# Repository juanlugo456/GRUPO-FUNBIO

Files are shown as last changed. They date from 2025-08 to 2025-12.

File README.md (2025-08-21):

# Grupo 1 FunBio
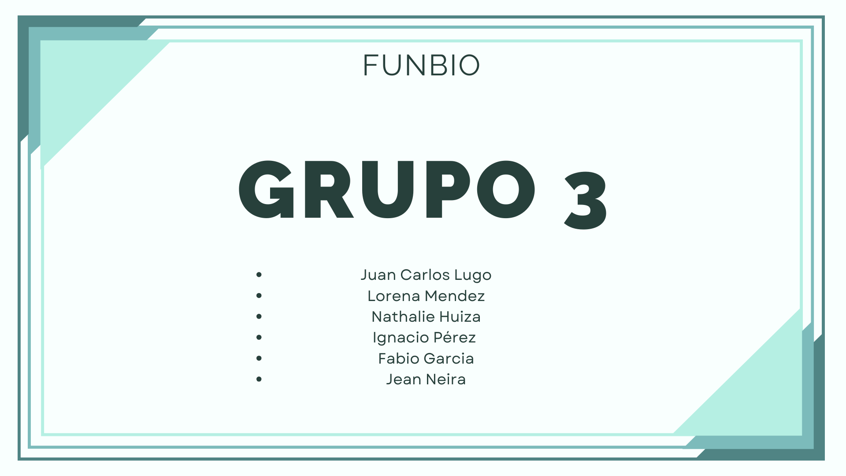
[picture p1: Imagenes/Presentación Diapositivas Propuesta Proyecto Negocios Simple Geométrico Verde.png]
Imagen_presentacion

## Equipo 3
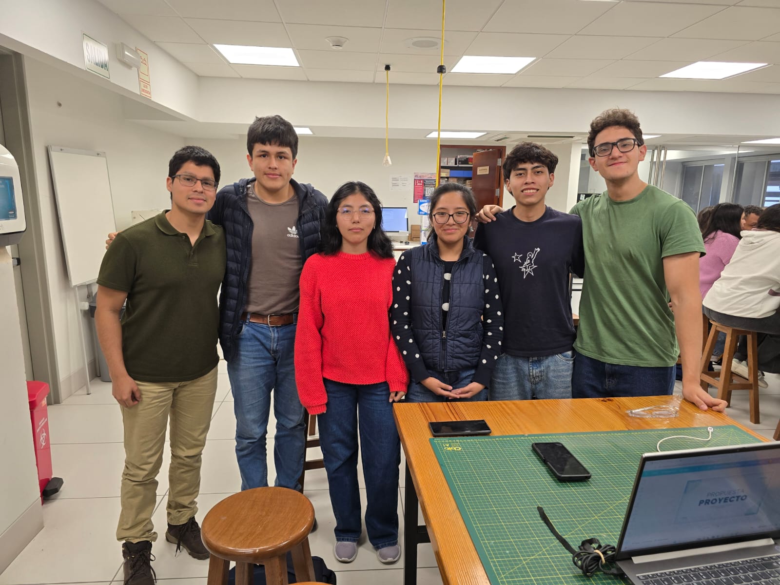
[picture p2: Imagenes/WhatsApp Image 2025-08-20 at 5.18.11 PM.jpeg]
Imagenfotogrupal

Somos alumnos de 4to ciclo de la carrera de Ingeniería Biomédica y estamos aquí para hacer el mundo un lugar mejor =).

## Miembros 
### Juan Carlos Lugo Rodriguez
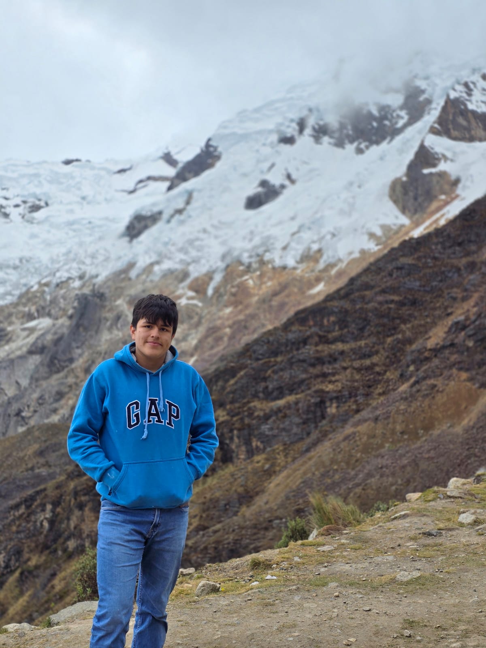
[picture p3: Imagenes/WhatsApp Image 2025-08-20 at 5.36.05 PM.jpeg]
Imagenfoto1
  
Edad:19 años    
Rol: Coordinador  
Responsabilidades:
- Estar pendientes de los avances del grupo
- Colaborar y ayudar en los avances
- Envio de los trabajos al Blackboard
### Ignacio Pérez Vargas
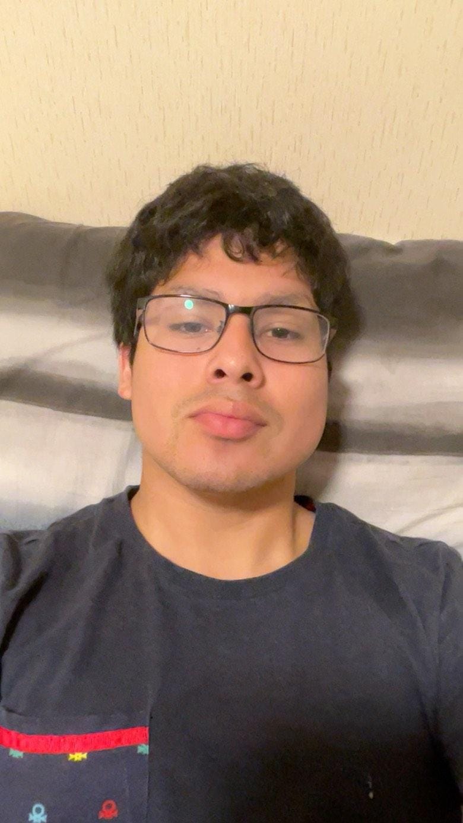
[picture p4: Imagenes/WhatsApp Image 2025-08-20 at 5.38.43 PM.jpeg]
Imagenfoto2
  
Edad: 18 años  
Rol: Programador y Prototipado  
Responsabilidades:
- Diseño 3D
- Elaboración de presentaciones e informes
- Prueba y ajuste.
### Lorena Mendez Saavedra  
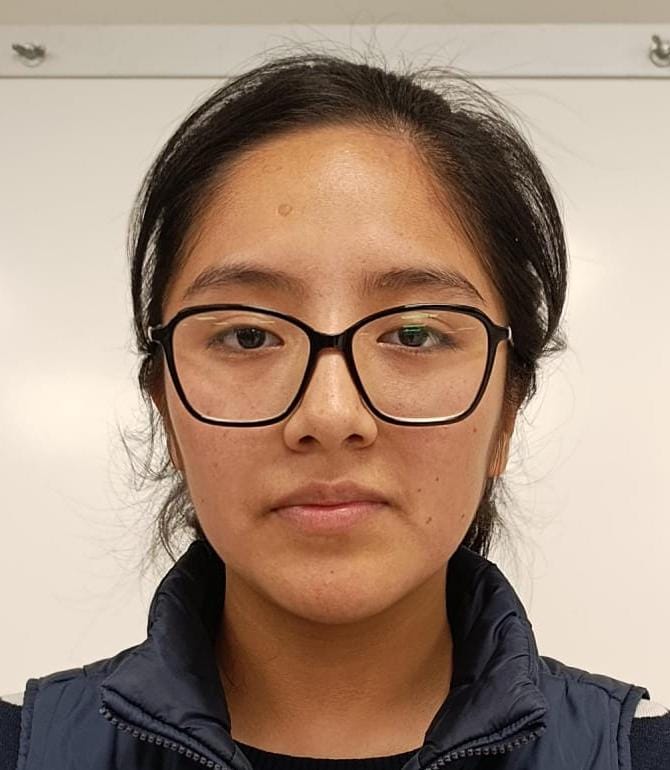
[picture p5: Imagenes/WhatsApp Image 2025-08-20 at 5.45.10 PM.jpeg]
Imagenfoto4
  
Edad: 18 años  
Rol: Gestor de repositorio  
Responsabilidades: 
- Actualizar información del trabajo
- Descargar y subir archivos(Repositorio)
### Nathalie Huiza  
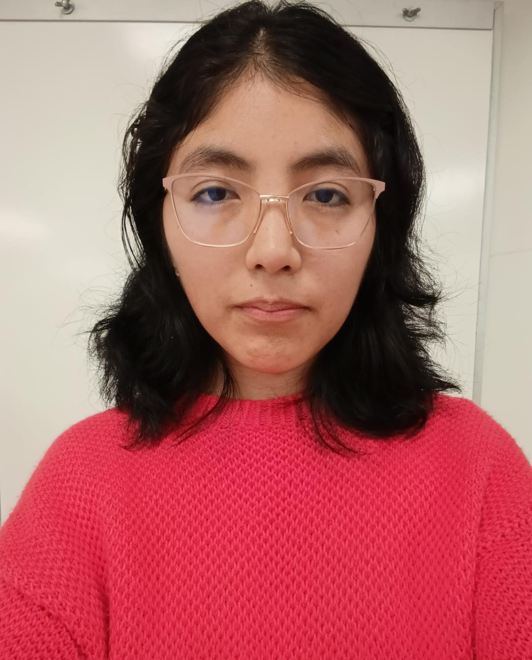
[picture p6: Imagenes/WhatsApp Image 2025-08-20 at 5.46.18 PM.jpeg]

Edad: 18  
Rol: Prototipado y armado  
Responsabilidad: 
- Diseño y prototipado
- Actualizar  información
- Pruebas finales
### Jean Neira
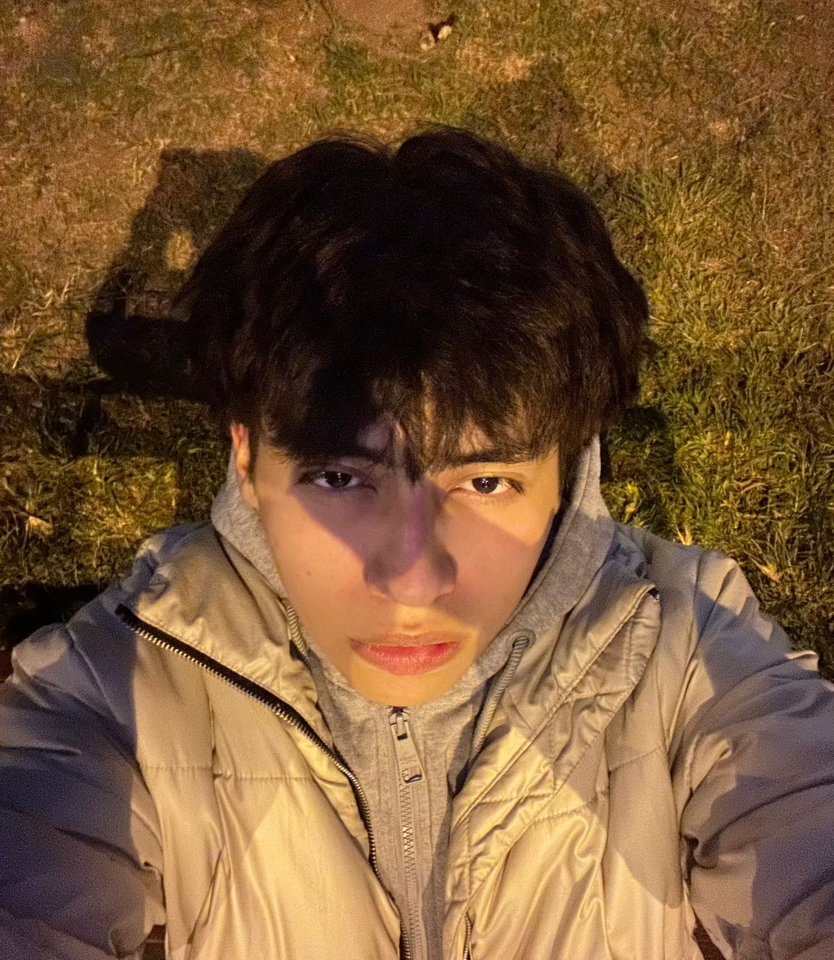
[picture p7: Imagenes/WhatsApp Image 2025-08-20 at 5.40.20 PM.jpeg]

Edad: 18  
Rol: Diseño y prototipado  
Responsabilidad: 
- Pruebas finales
- Registro de los materiales
- Apoyo moral
### Fabio Iván García Soto
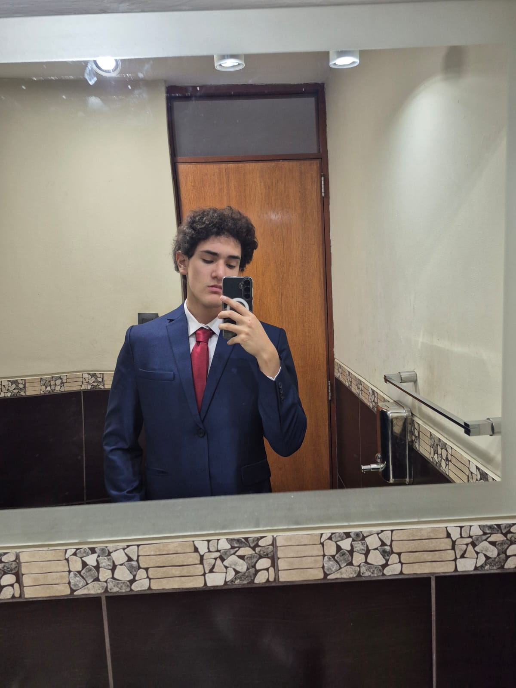
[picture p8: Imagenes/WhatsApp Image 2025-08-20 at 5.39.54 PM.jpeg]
Imagenfoto6

Edad: 19 años  
Rol: Diseño y programación  
Responsabilidades:
- Programación del prototipo
- Verificación del correcto funcionamiento del prototipo
- Prueba y ajuste.

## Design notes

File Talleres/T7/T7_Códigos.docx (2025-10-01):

Actividad 1_ Código

#include <Wire.h>

#include <LiquidCrystal_I2C.h>

#include <BluetoothSerial.h>

BluetoothSerial SerialBT;

LiquidCrystal_I2C lcd(0x27, 16, 2); // Dirección I2C del LCD (puede ser 0x3F en algunos módulos)

void setup() {

Serial.begin(115200);

SerialBT.begin("ESP32_LCD"); // Nombre Bluetooth

lcd.init();

lcd.backlight();

lcd.setCursor(0, 0);

lcd.print("Esperando BT...");

}

void loop() {

if (SerialBT.available()) {

String mensaje = SerialBT.readStringUntil('\n'); // Espera mensaje terminado en nueva línea

lcd.clear();

lcd.setCursor(0, 0);

// Si el mensaje es muy largo, dividir en dos líneas

if (mensaje.length() <= 16) {

lcd.print(mensaje);

} else {

lcd.print(mensaje.substring(0, 16));

lcd.setCursor(0, 1);

lcd.print(mensaje.substring(16, 32)); // 2da línea hasta 16 más

}

Serial.println("Mensaje recibido: " + mensaje);

}

}


Actividad 2_Código

#include <ESP32Servo.h>

#include "BluetoothSerial.h"

Servo servo;

BluetoothSerial BT;

const int SERVO_PIN = 2; // pin GPIO2 para el servo

String inbuf;

void setup() {

// Inicializa servo

ESP32PWM::allocateTimer(0);

ESP32PWM::allocateTimer(1);

ESP32PWM::allocateTimer(2);

ESP32PWM::allocateTimer(3);

servo.setPeriodHertz(50);

servo.attach(SERVO_PIN, 500, 2400);

servo.write(90); // posición inicial al centro

// Inicializa Bluetooth

BT.begin("ESP32_SERVO"); // Nombre para emparejar desde el celular

// BT.setPin("1234"); // Opcional: PIN de emparejamiento

}

void loop() {

while (BT.available()) {

char c = (char)BT.read();

if (c == '\r') continue; // Ignora retorno de carro

if (c == '\n') { // Fin de línea = comando completo

int angulo = inbuf.toInt(); // convierte a número

angulo = constrain(angulo, 0, 180); // limita entre 0 y 180

servo.write(angulo); // mueve el servo

BT.printf("Servo movido a %d grados\n", angulo);

inbuf = "";

} else {

inbuf += c;

if (inbuf.length() > 5) inbuf = ""; // seguridad

}

}

}

Codigo final de la 2da activdad

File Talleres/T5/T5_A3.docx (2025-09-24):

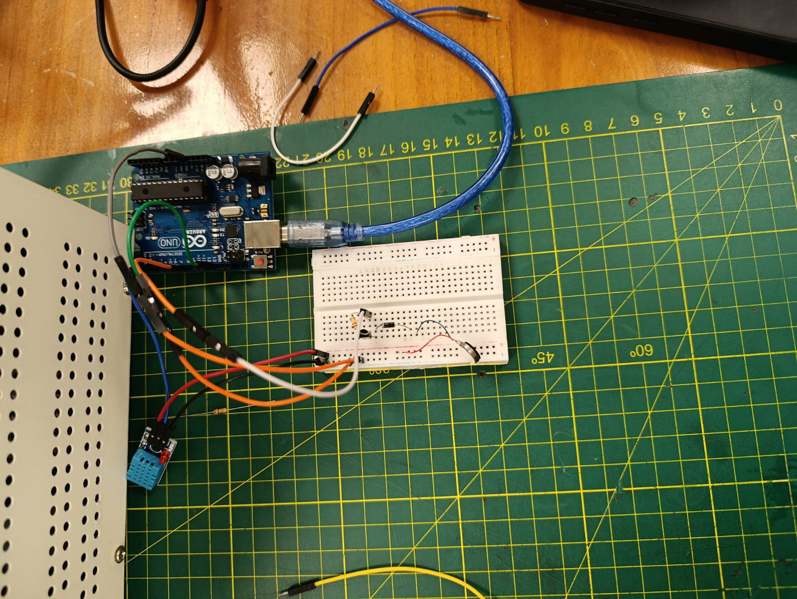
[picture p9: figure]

Código 3

#include <DHT.h>

#define DHTPIN 2 // Pin de datos del DHT11
#define DHTTYPE DHT11 // Tipo de sensor
#define MOTOR_PIN 9 // Pin PWM conectado a la base del 2N2222 (con resistencia)

DHT dht(DHTPIN, DHTTYPE);

void setup() {
Serial.begin(9600);
dht.begin();
pinMode(MOTOR_PIN, OUTPUT);
}

void loop() {
delay(2000); // DHT11 necesita tiempo entre lecturas

float temp = dht.readTemperature(); // Lee temperatura en °C

if (isnan(temp)) {
Serial.println("Error leyendo del DHT11!");
return;
}

Serial.print("Temperatura: ");
Serial.print(temp);
Serial.println(" *C");

int pwmValue = 0;

// Rango 1: 25–28 °C → Sin vibración
if (temp >= 25 && temp < 28) {
pwmValue = 0;
}
// Rango 2: 28–31 °C → Vibración media
else if (temp >= 28 && temp < 31) {
pwmValue = 128; // 50% duty cycle (0-255)
}
// Rango 3: 31–34 °C → Vibración alta
else if (temp >= 31 && temp <= 34) {
pwmValue = 220; // ~85% duty cycle
}
// Fuera de rango → motor apagado
else {
pwmValue = 0;
}

analogWrite(MOTOR_PIN, pwmValue);
}

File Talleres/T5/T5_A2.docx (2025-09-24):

“Código A2”
#include <Servo.h>

Servo servo;

int angulo;

int dato;

int pulso;

const int ledRojo = 8; // LED de alerta en pin 8

void setup() {

servo.attach(2); // Servo en pin 2

pinMode(ledRojo, OUTPUT);

Serial.begin(9600);

}

void loop() {

// Leer valor del flex sensor (0-1023)

dato = analogRead(A0);

// Mapear a ángulo de 0° a 270° (ajusta los valores mínimos y máximos de tu flex)

angulo = map(dato, 767, 964, 0, 270);

angulo = constrain(angulo, 0, 270); // Evitar valores fuera de rango

// Convertir ángulo a pulso (500–2400 µs)

pulso = map(angulo, 0, 270, 500, 2400);

// Enviar pulso al servo

servo.writeMicroseconds(pulso);

// Encender LED rojo si llega al máximo (270°)

if (angulo >= 270) {

digitalWrite(ledRojo, HIGH);

} else {

digitalWrite(ledRojo, LOW);

}

// Mostrar en Serial: ADC, pulso y ángulo

Serial.print("ADC: ");

Serial.print(dato);

Serial.print(" | Pulso (us): ");

Serial.print(pulso);

Serial.print(" | Angulo: ");

Serial.println(angulo);

delay(50);

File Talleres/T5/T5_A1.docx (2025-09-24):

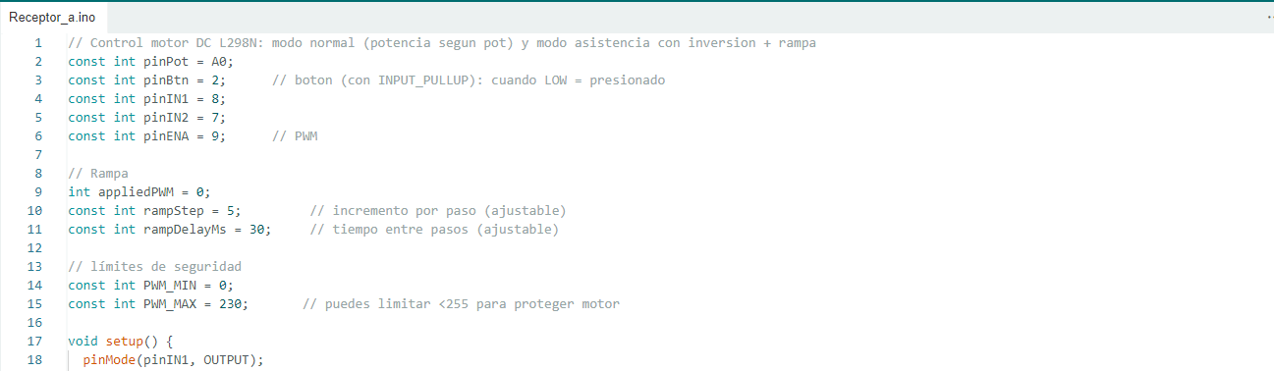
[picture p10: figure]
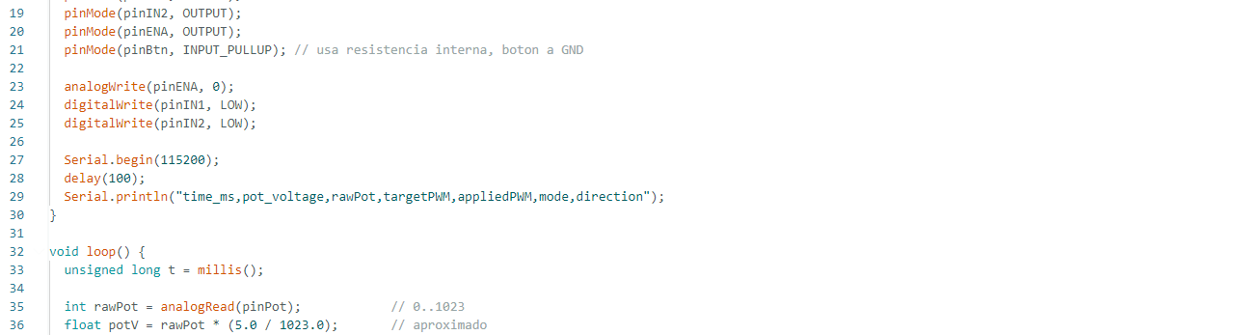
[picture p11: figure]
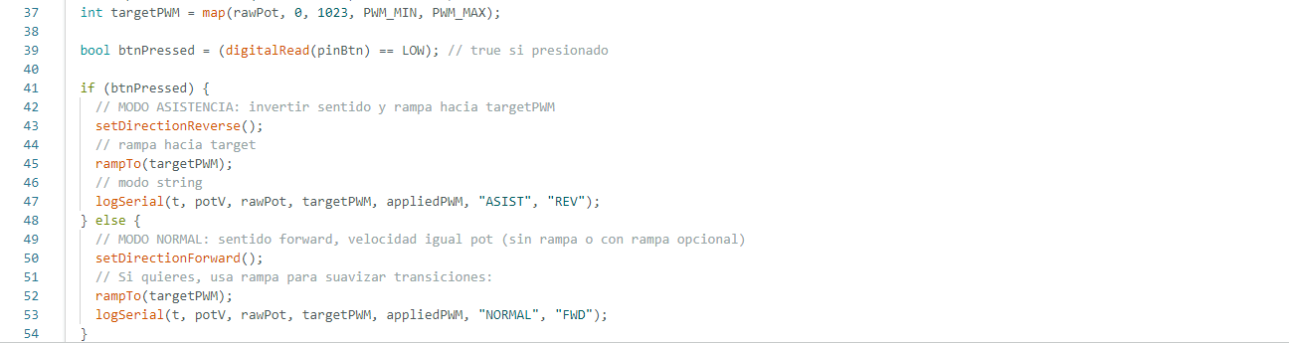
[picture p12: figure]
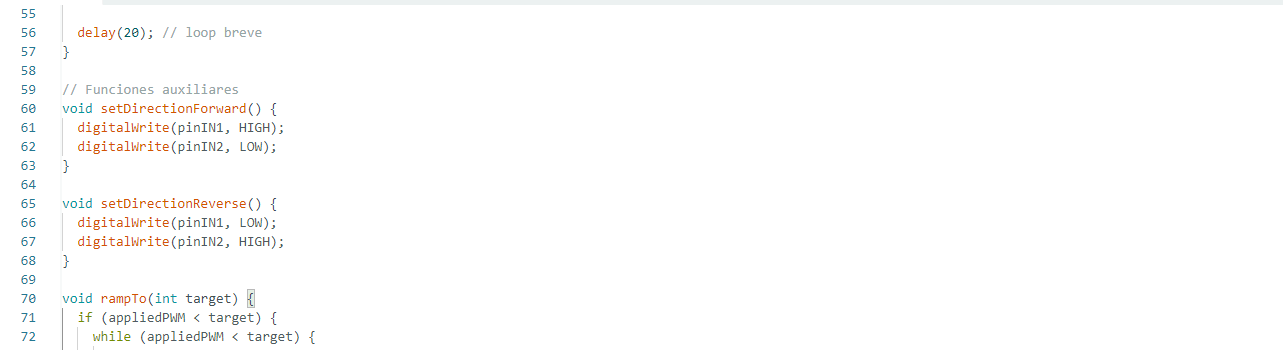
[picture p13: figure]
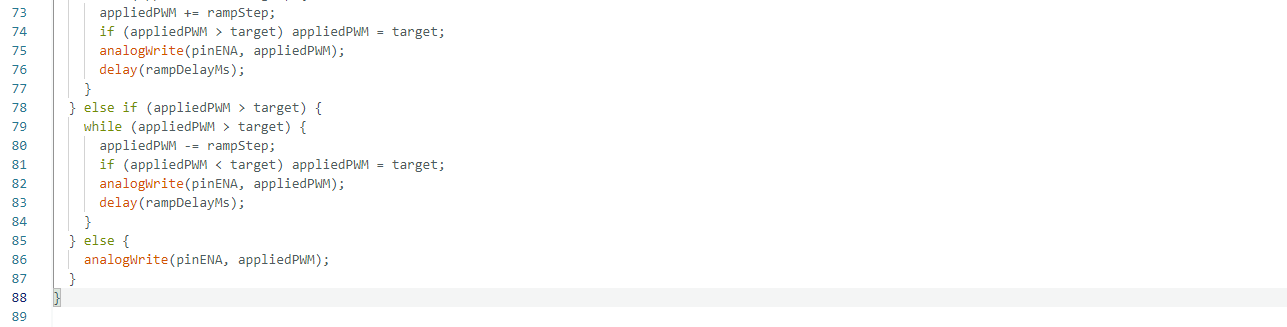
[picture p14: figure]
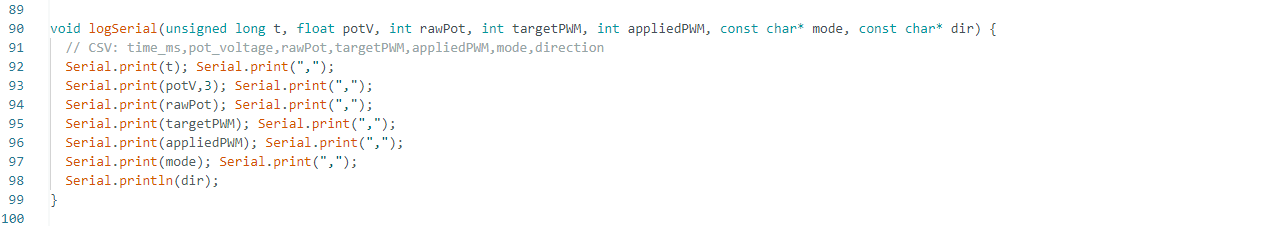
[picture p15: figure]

Còdigo

// Control motor DC L298N: modo normal (potencia segun pot) y modo asistencia con inversion + rampa

const int pinPot = A0;

const int pinBtn = 2; // boton (con INPUT_PULLUP): cuando LOW = presionado

const int pinIN1 = 8;

const int pinIN2 = 7;

const int pinENA = 9; // PWM

// Rampa

int appliedPWM = 0;

const int rampStep = 5; // incremento por paso (ajustable)

const int rampDelayMs = 30; // tiempo entre pasos (ajustable)

// límites de seguridad

const int PWM_MIN = 0;

const int PWM_MAX = 230; // puedes limitar <255 para proteger motor

void setup() {

pinMode(pinIN1, OUTPUT);

pinMode(pinIN2, OUTPUT);

pinMode(pinENA, OUTPUT);

pinMode(pinBtn, INPUT_PULLUP); // usa resistencia interna, boton a GND

analogWrite(pinENA, 0);

digitalWrite(pinIN1, LOW);

digitalWrite(pinIN2, LOW);

Serial.begin(115200);

delay(100);

Serial.println("time_ms,pot_voltage,rawPot,targetPWM,appliedPWM,mode,direction");

}

void loop() {

unsigned long t = millis();

int rawPot = analogRead(pinPot); // 0..1023

float potV = rawPot * (5.0 / 1023.0); // aproximado

int targetPWM = map(rawPot, 0, 1023, PWM_MIN, PWM_MAX);

bool btnPressed = (digitalRead(pinBtn) == LOW); // true si presionado

if (btnPressed) {

// MODO ASISTENCIA: invertir sentido y rampa hacia targetPWM

setDirectionReverse();

// rampa hacia target

rampTo(targetPWM);

// modo string

logSerial(t, potV, rawPot, targetPWM, appliedPWM, "ASIST", "REV");

} else {

// MODO NORMAL: sentido forward, velocidad igual pot (sin rampa o con rampa opcional)

setDirectionForward();

// Si quieres, usa rampa para suavizar transiciones:

rampTo(targetPWM);

logSerial(t, potV, rawPot, targetPWM, appliedPWM, "NORMAL", "FWD");

}

delay(20); // loop breve

}

// Funciones auxiliares

void setDirectionForward() {

digitalWrite(pinIN1, HIGH);

digitalWrite(pinIN2, LOW);

}

void setDirectionReverse() {

digitalWrite(pinIN1, LOW);

digitalWrite(pinIN2, HIGH);

}

void rampTo(int target) {

if (appliedPWM < target) {

while (appliedPWM < target) {

appliedPWM += rampStep;

if (appliedPWM > target) appliedPWM = target;

analogWrite(pinENA, appliedPWM);

delay(rampDelayMs);

}

} else if (appliedPWM > target) {

while (appliedPWM > target) {

appliedPWM -= rampStep;

if (appliedPWM < target) appliedPWM = target;

analogWrite(pinENA, appliedPWM);

delay(rampDelayMs);

}

} else {

analogWrite(pinENA, appliedPWM);

}

}

void logSerial(unsigned long t, float potV, int rawPot, int targetPWM, int appliedPWM, const char* mode, const char* dir) {

// CSV: time_ms,pot_voltage,rawPot,targetPWM,appliedPWM,mode,direction

Serial.print(t); Serial.print(",");

Serial.print(potV,3); Serial.print(",");

Serial.print(rawPot); Serial.print(",");

Serial.print(targetPWM); Serial.print(",");

Serial.print(appliedPWM); Serial.print(",");

Serial.print(mode); Serial.print(",");

Serial.println(dir);

}

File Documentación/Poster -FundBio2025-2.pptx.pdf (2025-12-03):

# MOTIO

Analisis del caso/problemática | Requerimientos de diseño

Fabio García, Nathalie Huiza, Juan Lugo, Lorena Méndez, Jean Neira e Ignacio Pérez ¹Fundamentos de Biodiseño 2025-2, Ingeniería Biomédica, Facultad de Ciencias e Ingenieria

## Objetivos

### Diagramas electrónicos

## Diseño/Prototipado

Funcionales
Detectar FOG con alta precisión (≥85% sensibilidad). Activar vibración automática en menos de 500 ms. Procesar datos en tiempo real desde los sensores FSR. Estructura / Hardware
Plantilla flexible y delgada, compatible con tallas estándar. Módulo de cinturón compacto y liviano.
Batería recargable con autonomía mínima de 8–10 horas. Seguridad
Sistema fail-safe ante fallos o batería baja.
Materiales biocompatibles (ISO 10993).
Usabilidad
Fácil de colocar (<60 segundos). Vibración perceptible y no molesta.

El prototipo identificó variaciones en la presión del pie asociadas al freezing of gait y activó una vibración háptica de forma automática para facilitar el inicio del movimiento.
Este método coincide con hallazgos que muestran que la estimulación táctil puede mejorar la fluidez del movimiento y reducir los bloqueos en personas con Parkinson [Charco Neurotech, 2025].
Tecnologías como Walkasins demuestran que la retroalimentación sensorial en los pies puede mejorar tanto el equilibrio como la movilidad [RxFunction, 2024].
Aunque aún no existen pruebas clínicas formales, los resultados iniciales sugieren un funcionamiento estable del ciclo detección con vibración, con potencial para disminuir el riesgo de caídas y aumentar la independencia del usuario.

## Resultados y Discusión

## Diseño/ Protitipado

La estimulación háptica
automática demuestra
potencial para mejorar la
continuidad de la marcha
y reducir riesgo de caídas

Se recomienda el realizar
pruebas con más usuarios
para validar precisión y
ajustar sensibilidad.

### Boceto

## Modelado 3D

Reference 1: RxFunction Inc., “Clinical research on Walkasins sensory prosthesis,” 2024. [Online]. Available: RxFunction Inc. (2024). Clinical research on Walkasins sensory prosthesis. Recuperado de https://rxfunction.com/healthcare-professionals/clinical-research/ Reference 2: Queen Mary University of London, “Cue1 device improves motor and non-motor outcomes in Parkinson’s disease: Findings
from | a | double-blind, | sham-controlled | randomized | study,” | Charco | Neurotech, | 2025. | [Online]. | Available:
https://charconeurotech.com/blog/2025/08/05/cue1-device-improves-motor-and-non-motor-outcomes-in-parkinsons-disease-findings-from-a-qmul-double-blind-sham-controlled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

## EQUIPO 3 - GRUPO 1

Reference 3: [1] Ministerio de Salud del Perú (MINSA), “El Parkinson afecta a unas 30 mil personas en el Perú”, Gobierno del Perú, 11 abr. 2016. [En línea]. Disponible en: https://www.gob.pe/institucion/minsa/noticias/27375-el-parkinson-afecta-a-unas-30-mil-personas-en-el-peru. (https://www.gob.pe/institucion/minsa/noticias/27375-el-parkinson-afecta-a-unas-30-mil-personas-en-el-peru)

Detectar episodios
de FOG en tiempo
real utilizando un
algoritmo ligero
embebido

## mil personas +30

sufren de Parkinson en
el Perú [1]

Las personas con enfermedad de Parkinson presentan alteraciones motoras progresivas que afectan equilibrio, coordinación y continuidad de la marcha.
El Freezing of Gait (FOG) es uno de los eventos más incapacitantes: bloqueo súbito e involuntario del movimiento pese a la intención de caminar. Ocurre en más del 50 % de los pacientes en etapas moderadas, aumentando significativamente el riesgo de caídas y la pérdida de autonomía.

## Prototipo Físico

Monitorear el patrón
de presión plantar
mediante una
plantilla sensorizada

Aumentar la
autonomía del
usuario
reduciendo el
riesgo de caídas

Garantizar que el
dispositivo sea
cómodo, seguro, no
invasivo y apto para
uso diario
Generar un estímulo
háptico automático,
rápido y discreto que
ayude al paciente a
retomar la marcha

## Conclusiones y recomendaciones

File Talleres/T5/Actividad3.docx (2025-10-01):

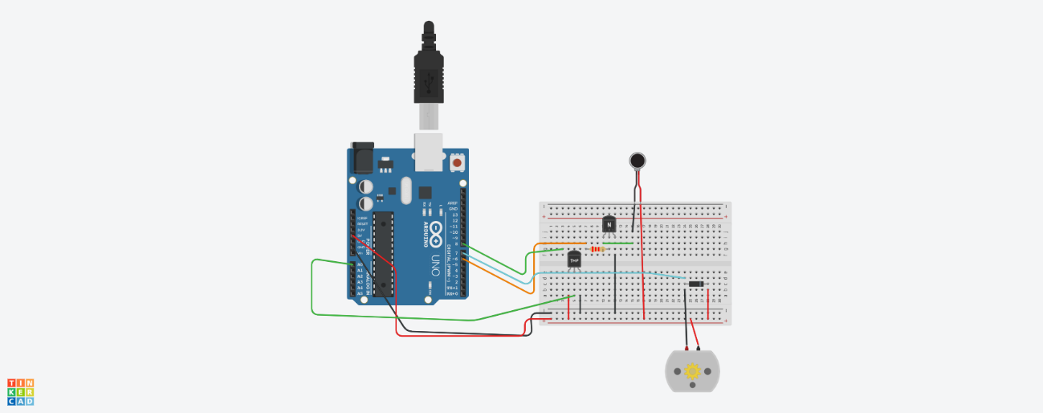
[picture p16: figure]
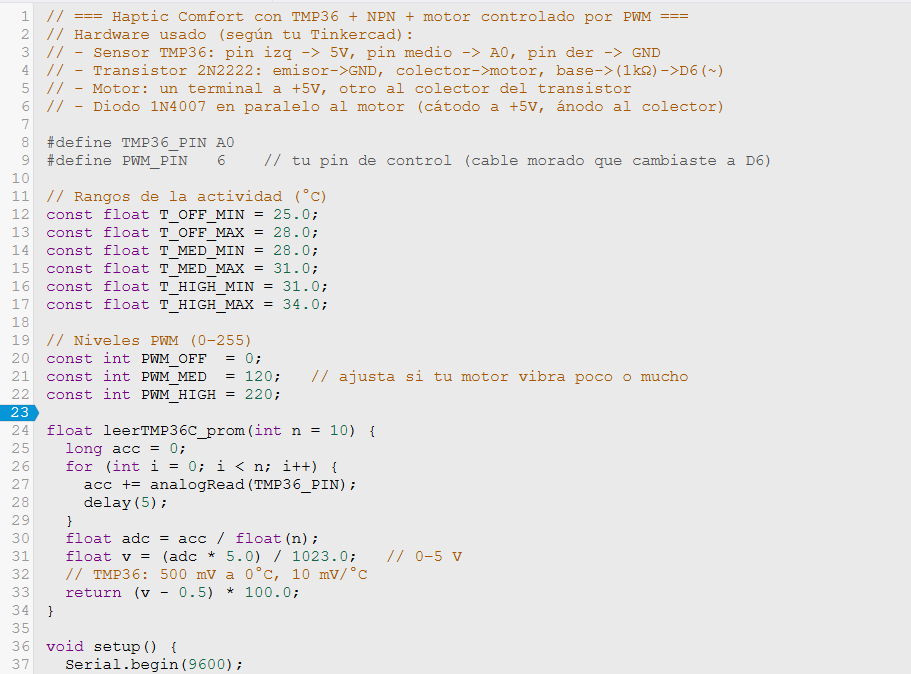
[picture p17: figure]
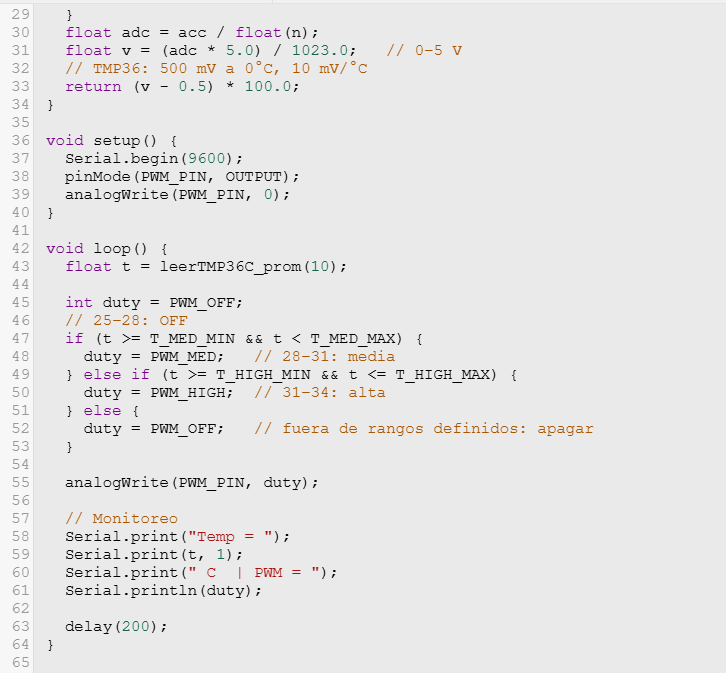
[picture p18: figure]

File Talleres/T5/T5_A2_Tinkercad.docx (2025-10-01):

T5_A2_Tinkercad

https://www.tinkercad.com/things/ibYNlmgGIRk-t52a-medias?sharecode=PGFiDS4-p6gbItO99VYVsooADr4LZbbFHK1OzBIqJ5s

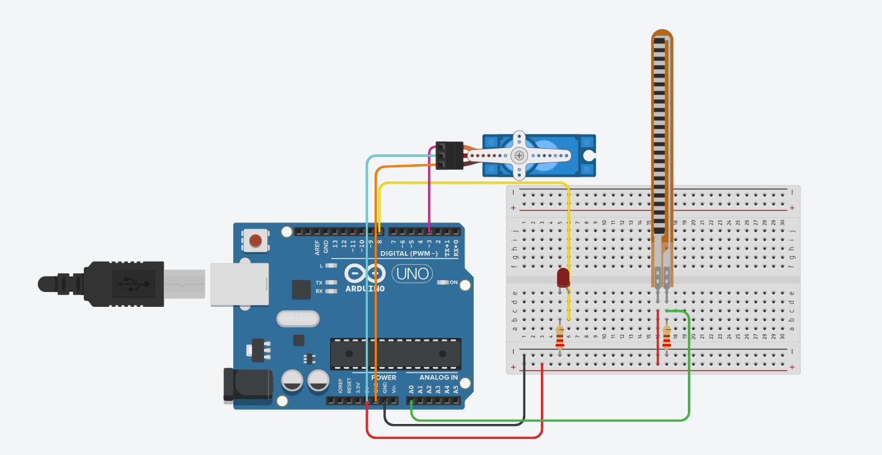
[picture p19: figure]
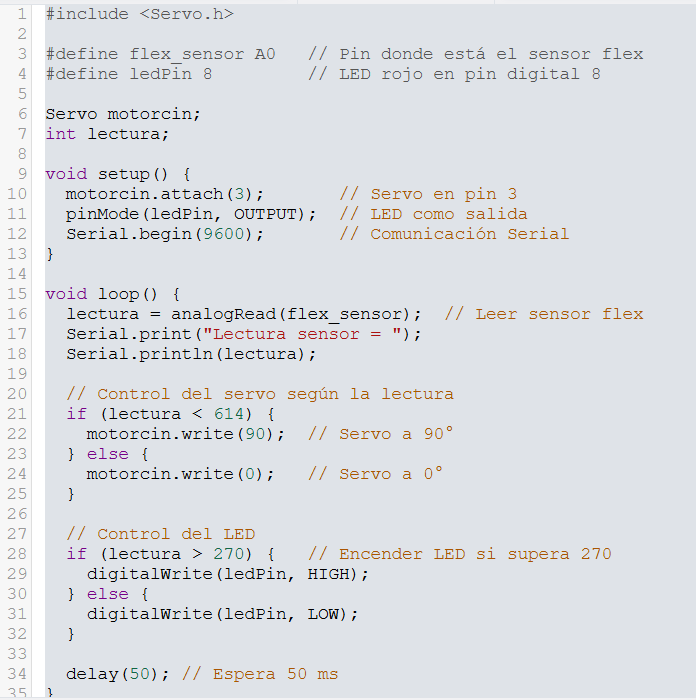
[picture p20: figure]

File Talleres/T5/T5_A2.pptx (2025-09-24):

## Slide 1

Video 2

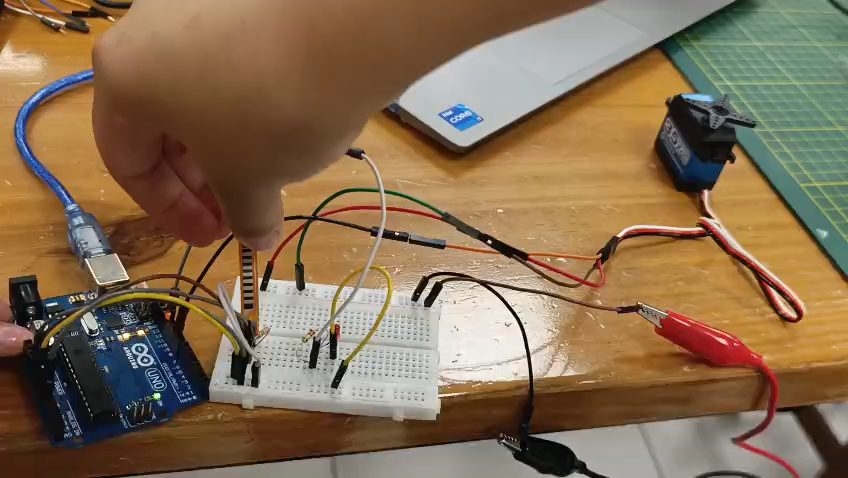
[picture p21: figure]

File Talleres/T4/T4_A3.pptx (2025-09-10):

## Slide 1

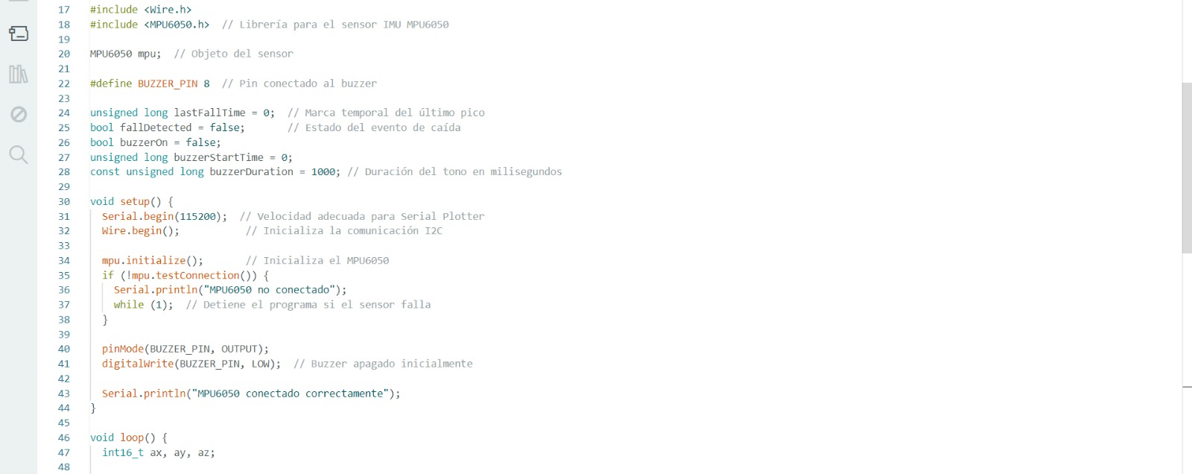
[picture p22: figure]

Código

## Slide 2

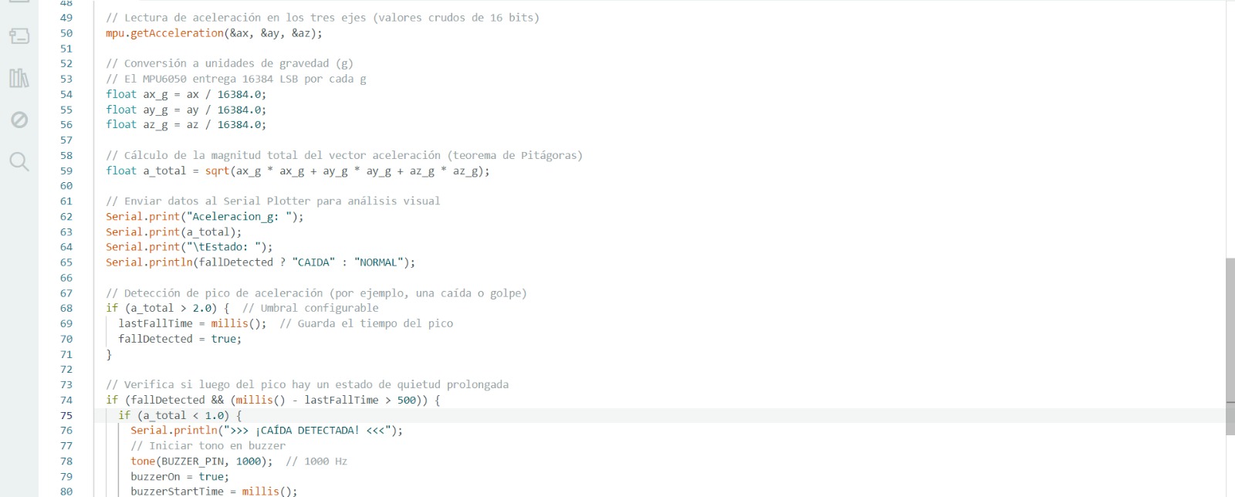
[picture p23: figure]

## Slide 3

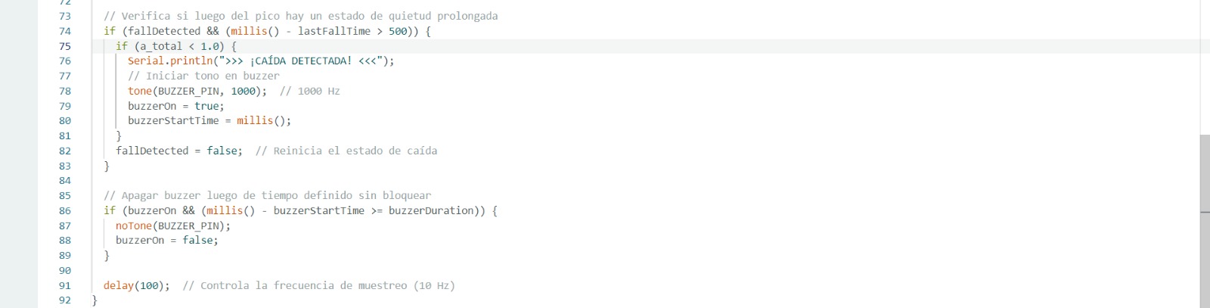
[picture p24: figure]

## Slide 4

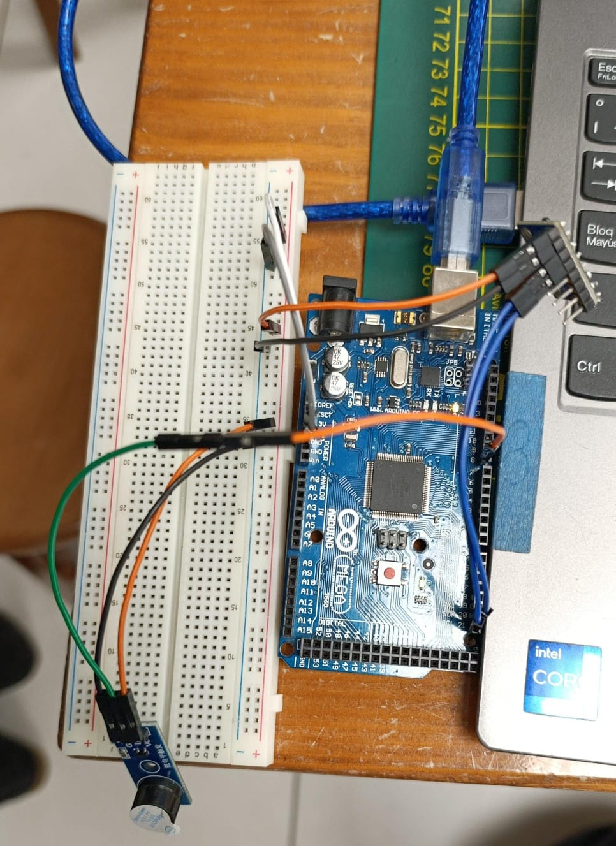
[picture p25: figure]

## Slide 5

Video

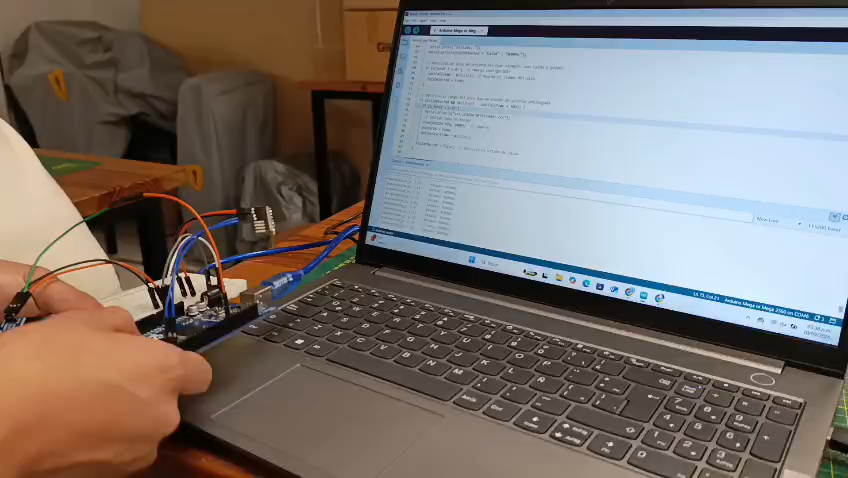
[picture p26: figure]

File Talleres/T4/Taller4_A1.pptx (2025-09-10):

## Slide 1

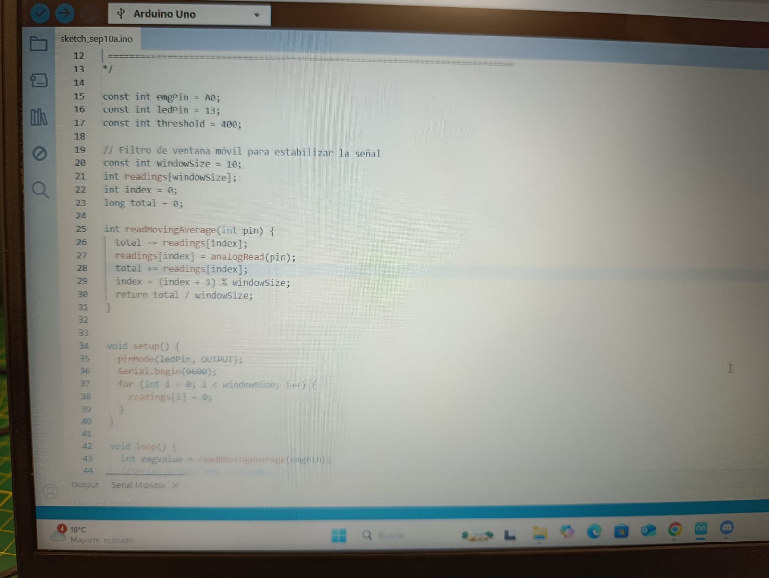
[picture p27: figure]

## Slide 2

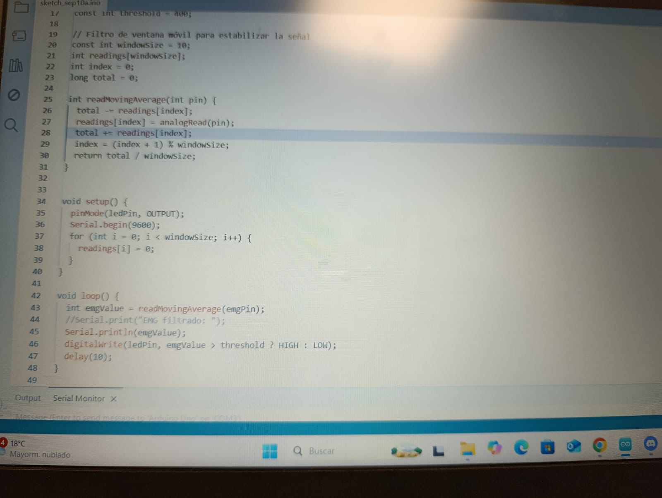
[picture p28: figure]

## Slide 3

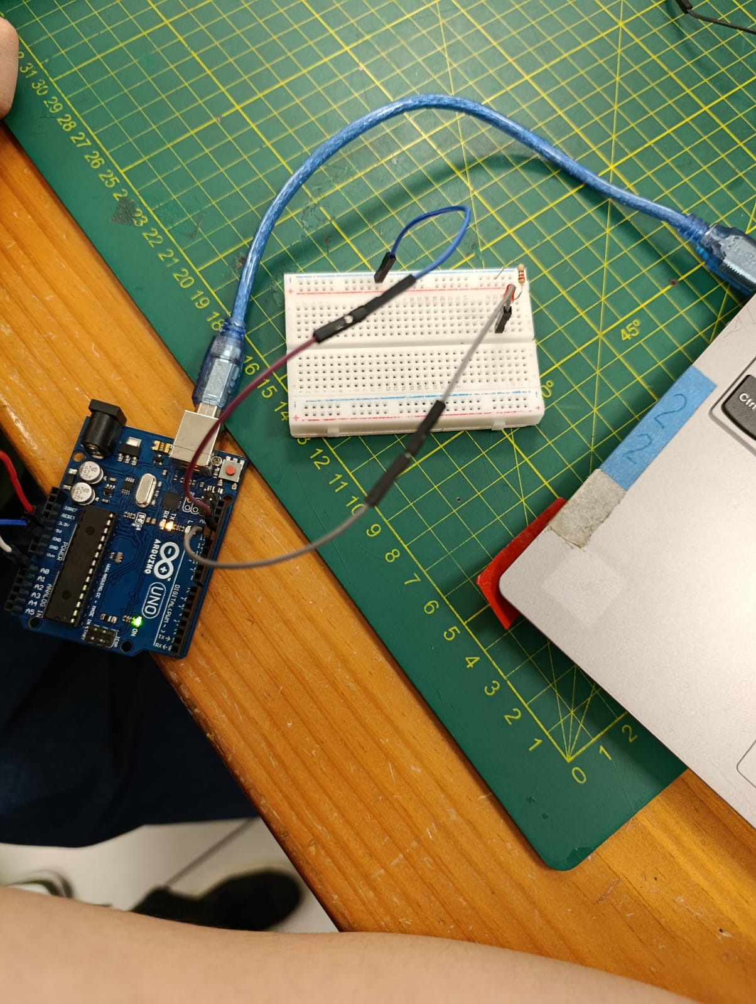
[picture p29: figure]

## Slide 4

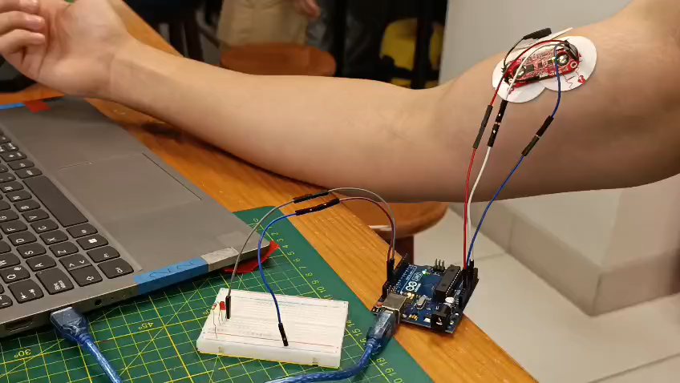
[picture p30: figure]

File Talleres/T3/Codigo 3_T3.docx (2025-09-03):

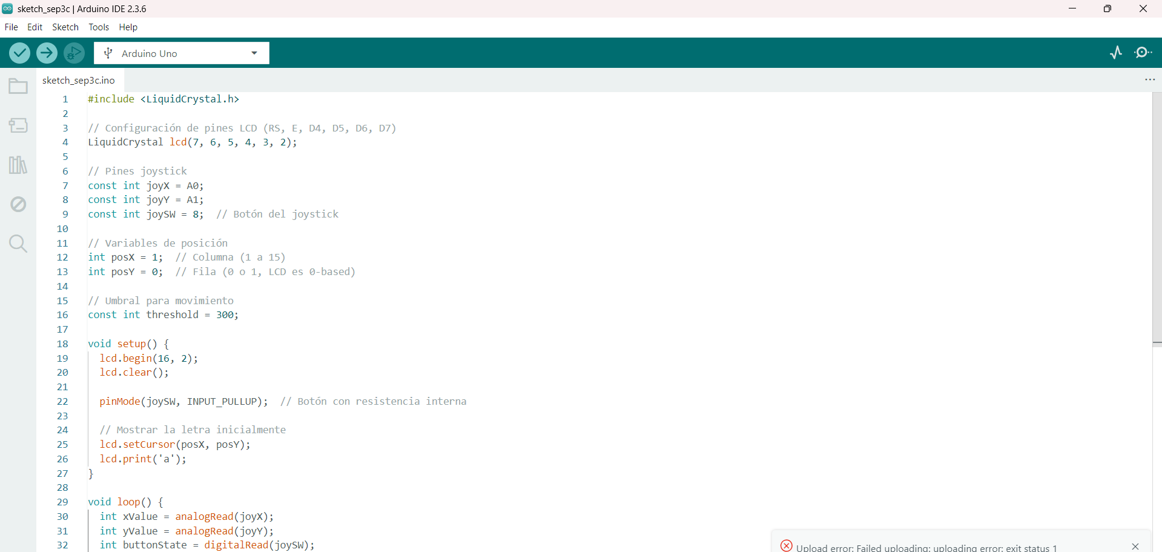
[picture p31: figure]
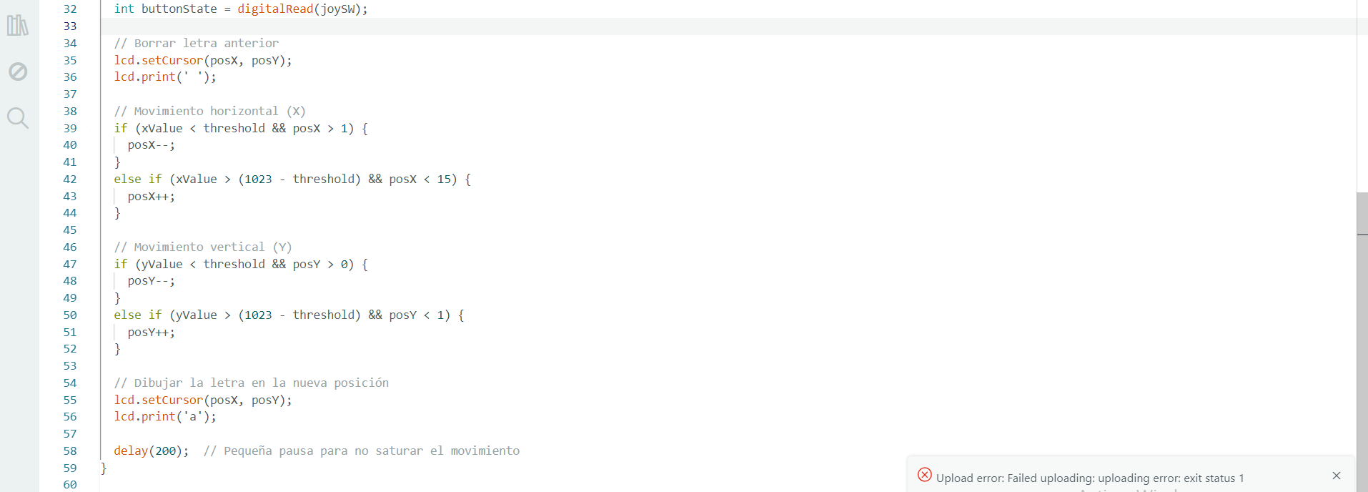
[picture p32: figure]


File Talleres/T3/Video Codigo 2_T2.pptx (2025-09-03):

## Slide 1


T2

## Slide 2


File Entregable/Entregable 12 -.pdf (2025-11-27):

# Entregable 12 - Grupo 3

# Fundamentos de Biodiseño

# Integrantes:

## Juan Carlos Lugo Lorena Mendez Nathalie Huiza Ignacio Pérez Fabio García Jean Neira

2025

### Plan de Usabilidad Final

Sección del plan | ¿Qué es? | ¿Qué hacer? | ¿Qué evidencia deben incluir?
1. Contexto de uso
| El prototipo está diseñado para personas diagnosticadas con la enfermedad de Parkinson, en etapas iniciales o moderadas, que presentan dificultades motoras y episodios de freezing of gait (FOG), pero conservan sus capacidades cognitivas y sensoriales suficientes para seguir instrucciones simples y comprender el funcionamiento del dispositivo.
| El sistema consiste en una plantilla inteligente con sensores de presión (FSR), conectada a un módulo vibratorio ubicado en un cinturón o tobillera, que detecta patrones anormales de presión plantar asociados a episodios de bloqueo de la marcha. Cuando se identifica un FOG, el dispositivo activa una vibración háptica inmediata

El prototipo está
pensado para
personas con
enfermedad de
Parkinson en etapa
inicial o moderada
que sufren
episodios de
freezing of gait
(FOG).

Se utilizará en
entornos
controlados, como
laboratorios o
clínicas de
rehabilitación, bajo
la supervisión de
un terapeuta.

El paciente colocará
la plantilla con
sensores FSR
dentro del calzado y
ajustará el módulo
vibratorio en el
cinturón, simulando
una sesión de
terapia física.

para estimular al
usuario a retomar el
movimiento.

En cuanto a su
aplicación, el
prototipo será
probado en
entornos
controlados, como
laboratorios o
clínicas de
rehabilitación, bajo
la supervisión de
un terapeuta o
evaluador. Su uso
busca reducir el
riesgo de caídas,
mejorar la
continuidad de la
marcha y aumentar
la independencia
funcional del
paciente, ofreciendo
una alternativa no
invasiva y práctica
para la
rehabilitación
motora.
2. Perfil del usuario
El perfil del usuario
corresponde a una
persona adulta
diagnosticada con
enfermedad de
Parkinson en etapa
intermedia, con
manifestaciones
motoras evidentes
pero que mantiene
autonomía parcial
en sus actividades
básicas. Presenta
episodios
ocasionales de
freezing of gait
(FOG), lo que
genera bloqueos
repentinos al
caminar, pero
conserva sus

Evaluación de
limitaciones:

Limitaciones
motoras:
- Característi
ca: Rigidez
muscular,
bradicinesia
y episodios
de freezing
of gait.
- Evidencia:
Examen
clínico típico
del
Parkinson:
lentitud de
movimiento,

(Datos del caso
seleccionado):

Limitaciones
motoras:
- Característi
ca: Rigidez
muscular,
bradicinesia
y marcha
festinante
con dificultad
para iniciar o
detener el
movimiento.
- Evidencia:
La paciente
presenta
temblor de

capacidades
cognitivas y
sensoriales
necesarias para
interactuar
adecuadamente con
el dispositivo.

bloqueos
durante la
marcha y
dificultad
para cambiar
de dirección.
- Impacto:
Dificulta el
desplazamie
nto fluido y
aumenta el
riesgo de
caídas.

Limitaciones
sensoriales:
- Característi
ca: Leve
disminución
de la
percepción
propioceptiv
a (sensación
del
movimiento
del cuerpo).
- Evidencia:
Se observa
pérdida de
coordinación
fina y menor
estabilidad al
caminar.
- Impacto:
Afecta la
capacidad
para
mantener el
equilibrio y
detectar
correctament
e el apoyo
del pie.

Limitaciones
cognitivas:
- Característi

reposo en
mano
derecha,
rigidez en
rueda
dentada,
pasos cortos
y dificultad
para
mantener el
equilibrio, lo
que provoca
caídas
frecuentes.

Limitacione
s
sensoriales
y de
equilibrio:
- Característi
ca:
Inestabilidad
postural y
alteración
del control
del equilibrio.
- Evidencia:
La paciente
muestra
desequilibrio
al caminar,
con caídas
recurrentes y
dificultad
para
mantener
una postura
estable al
realizar
cambios de
dirección.

Capacidades
cognitivas y de
comprensión:
- Característi
ca: Lúcida,

ca:
Procesamien
to mental
ligeramente
más lento,
pero
comprensión
conservada.
- Evidencia:
El paciente
sigue
órdenes y
entiende
instrucciones
, pero puede
requerir más
tiempo para
responder.
- Impacto: No
interfiere
significativa
mente con el
uso del
dispositivo.

Limitaciones de
comprensión:
- Característi
ca:
Comprensió
n del
lenguaje oral
y simbólico
intacta.
- Evidencia:
El paciente
entiende
señales
verbales y
reconoce
patrones
vibratorios.
- Impacto:
Puede usar
el dispositivo
sin
asistencia
constante.

orientada y
con
comprensión
conservada,
aunque con
leve
bradipsiquia.
- Evidencia:
La paciente
comprende y
sigue
instrucciones
, pero su
procesamien
to mental es
más lento, lo
que puede
afectar la
velocidad de
reacción
ante
estímulos o
bloqueos
durante la
marcha.

Estado emocional
y social:
- Característi
ca:
Dependencia
parcial y
riesgo de
aislamiento
social por
movilidad
limitada.
- Evidencia:
Vive con su
esposo y
cuenta con
apoyo
familiar, pero
su dificultad
para
desplazarse
limita la
participación
en
actividades

fuera del
hogar.
3. Análisis de tareas Identifica y descompone las acciones que el usuario debe realizar para utilizar correctamente el sistema. Este análisis permite reconocer posibles errores o dificultades en la interacción con el dispositivo.

Tareas principales:
1. Colocar la
plantilla
sensorizada en el
calzado.
2. Ajustar el cinturón
con el
módulo vibratorio.
3. Encender el
sistema y
verificar que esté
operativo.
4. Caminar 10–15
metros
siguiendo las
indicaciones
del evaluador.
5. Durante un
episodio
simulado de FOG,
el sistema debe
activar la
vibración.
6. Apagar el sistema
al finalizar.
Riesgos
potenciales:
mala colocación,
conexión deficiente,
batería baja
o vibración no
percibida o mal
leida.

Resultados de
pruebas piloto en
entorno controlado;
observaciones
sobre tiempos de
colocación,
respuesta del
sistema y
retroalimentación
del usuario.

Tabla de tareas y
riesgos; justificación
de criticidad, que
describe cada tarea,
su tipo, los posibles
riesgos asociados y
una breve
justificación de por
qué se considera
crítica.
4. Criterios de éxito
(requisitos de
usabilidad)

Define los
indicadores
medibles que
determinan si el
sistema es fácil,
eficiente, seguro y
satisfactorio para el
usuario. Estos
criterios sirven para
validar el
desempeño
funcional del
dispositivo

Eficacia: el sistema
debe detectar
correctamente
≥85% de episodios
simulados de FOG y
activar la vibración
en ≤500 ms.
Eficiencia: el
usuario debe
colocarse el sistema
en menos de 2
minutos sin ayuda
externa.
Satisfacción: el

Evidencia: Datos de
tiempos de
colocación,
observaciones
directas de
desempeño y
encuestas de
satisfacción post
uso.

70% o más de los
usuarios reporta que
la vibración es clara,
útil y cómoda.
Seguridad: sin
molestias, dolor ni
alteraciones del
equilibrio durante la
marcha

## Tabla de tareas y riesgos

Tarea | Descripción | Tipo de tarea | Riesgo asociado | Justificación de criticidad
Encendido del sistema | El usuario o cuidador enciende el módulo central y verifica el encendido de la plantilla sensorizada y la conexión Bluetooth. | Inicial / Configuración | Falla de encendido o conexión Bluetooth. | Sin conexión, el sistema no puede registrar datos ni activar la vibración háptica.
Colocación de la plantilla, compartimient o (pantorrilla) y cinturón | El usuario coloca la plantilla dentro del calzado, ajusta en la pantorrilla el compartimento con los componentes del FSR y se coloca el cinturón con el módulo vibratorio alrededor de la cintura | Configuración / Preparación | Colocación incorrecta que impida una buena lectura de presión o genere incomodidad. | Un mal ajuste puede provocar lecturas erróneas, pérdida de datos o incomodidad física al usuario.
Calibración del sistema | El cuidador o terapeuta encargado activa la | Configuración | Calibración inexacta o falla del sensor. | Si la calibración es incorrecta, el sistema puede

calibración
inicial de los
sensores FSR
para ajustar la
sensibilidad de
presión plantar
según el peso
o necesidad
del usuario.

detectar falsos
positivos o no
reconocer un
episodio real
de FOG.

Monitoreo de
la marcha

Durante la
caminata, los
sensores de la
plantilla
registran la
presión plantar
y envían datos
al
microcontrolad
or para
analizar
patrones de
movimiento y
así poder
detectar si se
presenta una
caminata
irregular

Operativa
crítica

Error en la
transmisión de
datos o fallas
de lectura.

Si no se
detectan
correctamente
los patrones
de marcha, el
sistema no
podrá
reconocer un
episodio de
congelamiento
Activación del cue háptico (vibración) | Cuando el sistema detecta un episodio de “freezing of gait” (presión irregular) , activa los motores vibratorios del cinturón como estímulo táctil. | Automática / Seguridad | Falla en la activación o activación retardada. | La vibración tardía o ausente podría impedir que el paciente supere el bloqueo, aumentando el riesgo de caída.
Carga del dispositivo | El usuario conecta el módulo central a un puerto USB o cargador TP4056 para recargar la | Mantenimiento | Sobrecalenta miento o carga incorrecta de la batería. | Una mala manipulación durante la carga podría dañar el circuito o reducir la vida útil de la

| batería LiPo. | | | batería.
Apagado del sistema | El usuario apaga el sistema después de usarlo, desconectand o la plantilla y el cinturón. | Finalización | Apagado incorrecto o pérdida de configuración | Un apagado inadecuado puede provocar errores en la memoria o pérdida de calibración.

## Tabla de métricas objetivo

Criterio | Indicador de éxito | Métrica objetivo | Método de evaluación
Eficacia | Tasa de detección correcta de episodios de FOG basada en comparación con anotación clínica (“ground truth”). | ≥ 95 % de episodios de FOG detectados; ≥ 90 % de activaciones vibratorias ejecutadas dentro del rango de intensidad programado. | Registro simultáneo en video + anotación clínica + logs del sistema durante pruebas supervisadas.
Eficiencia | Tiempo entre la detección del patrón irregular de marcha y la activación del actuador vibratorio. | < 0.5 s desde la identificación del evento anómalo (variabilidad de paso / aceleración / giro). | Medición con cronómetro digital sincronizado con el software y análisis de timestamps del microcontrolador.
Satisfacción | Puntaje de usabilidad, comodidad y claridad de la retroalimentación vibratoria. | SUS ≥ 70 en usuarios con Parkinson leve-moderado. | Encuesta SUS posterior a pruebas de marcha en circuito supervisado.
Seguridad | Número de activaciones falsas que interrumpen o alteran la marcha. | ≤ 1 falso positivo por sesión (30–40 min). | Bitácora de campo + revisión de logs comparados con video.
Confiabilidad | Funcionamiento continuo sin bloqueos del | ≥ 60 min sin reinicios ni pérdida de paquetes > 2 %. | Pruebas de estrés en laboratorio + pruebas en campo

| microcontrolador, pérdida de comunicación o fallas del sensor. | | (caminata prolongada).
Accesibilidad | Diseño ergonómico de la plantilla y caja vibratoria que no afecte la marcha ni genere molestias. | Presión distribuida uniformemente (< 10 % de diferencia entre zonas). | Validación con análisis de presión plantar y retroalimentación del usuario.
Precisión del sensor | Diferencia entre lectura del sensor y medición de referencia en prueba controlada. | Error ≤ 5 %. | Calibración y validación técnica con equipo de referencia.

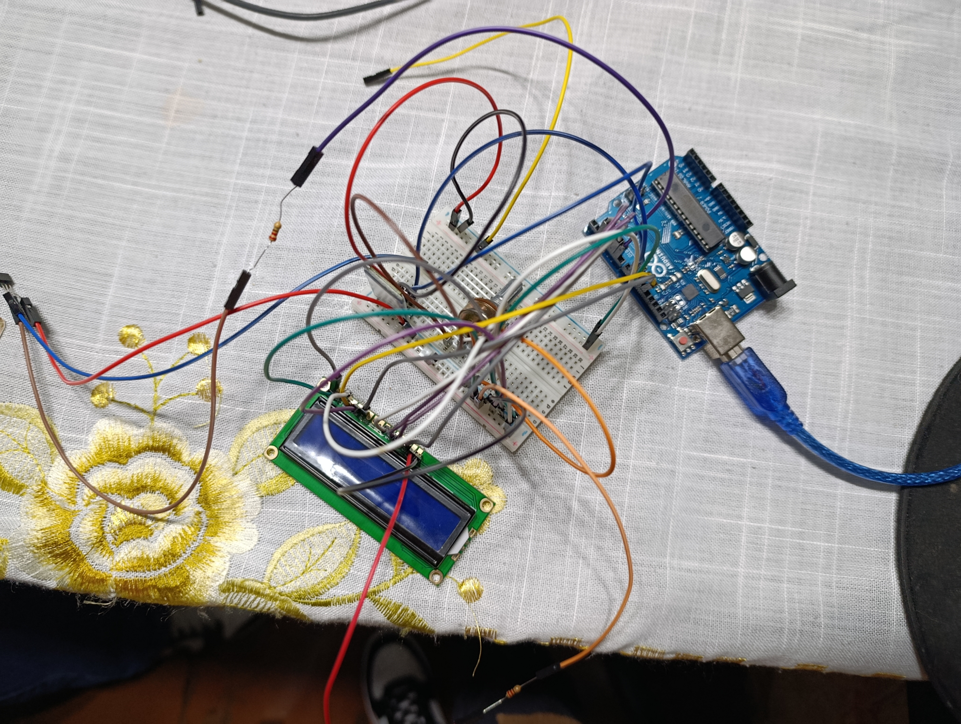
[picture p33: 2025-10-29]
Entregable/Entregable 9.jpg

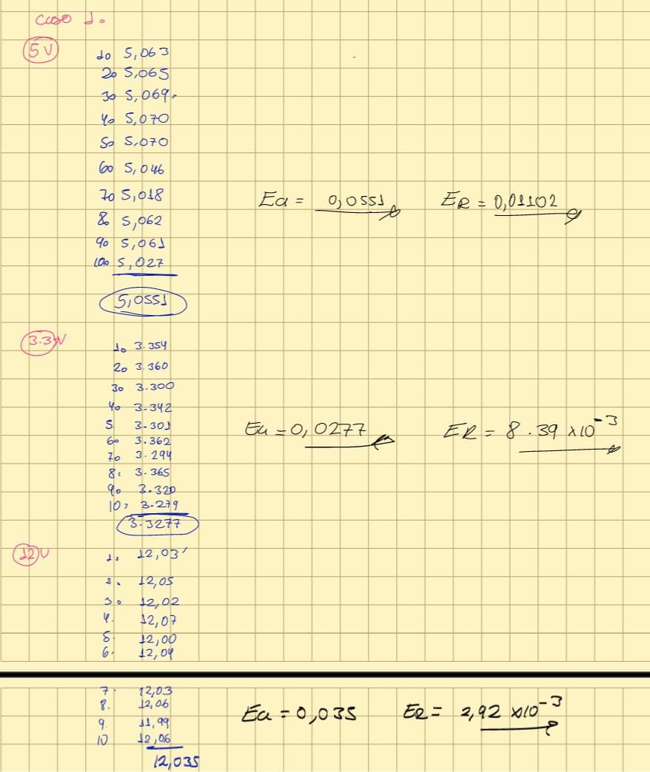
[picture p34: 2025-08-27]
Imagenes/IMG-20250827-WA0014.jpg

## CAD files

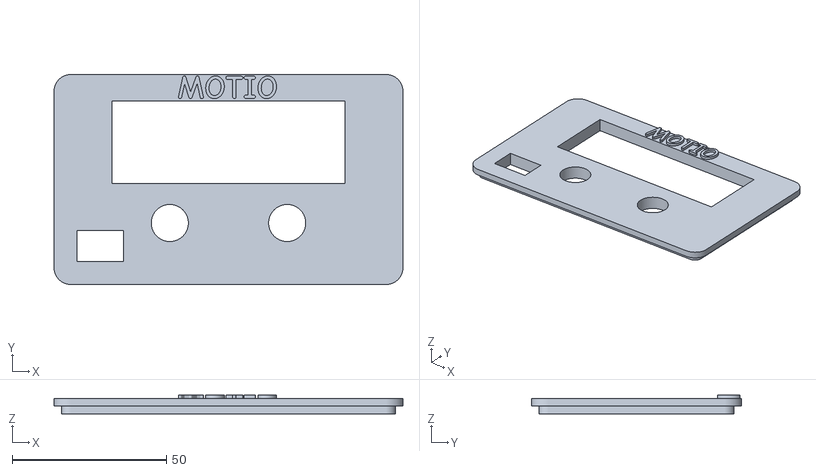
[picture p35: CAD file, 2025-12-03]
Hardware/Caja Modelo 3D/caja Cintura1 - Part 2.stl
113.0 x 68.0 x 6.00

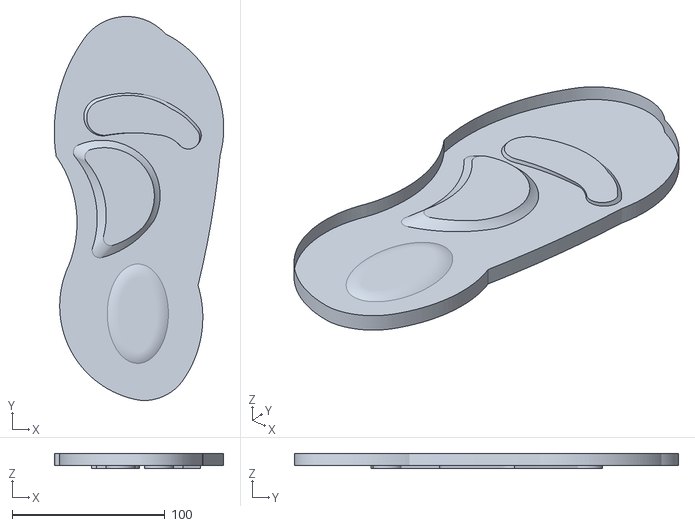
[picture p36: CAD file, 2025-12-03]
Hardware/Plantilla Modelo 3D/Parte_arriba P.stl
110.9 x 251.3 x 10.0

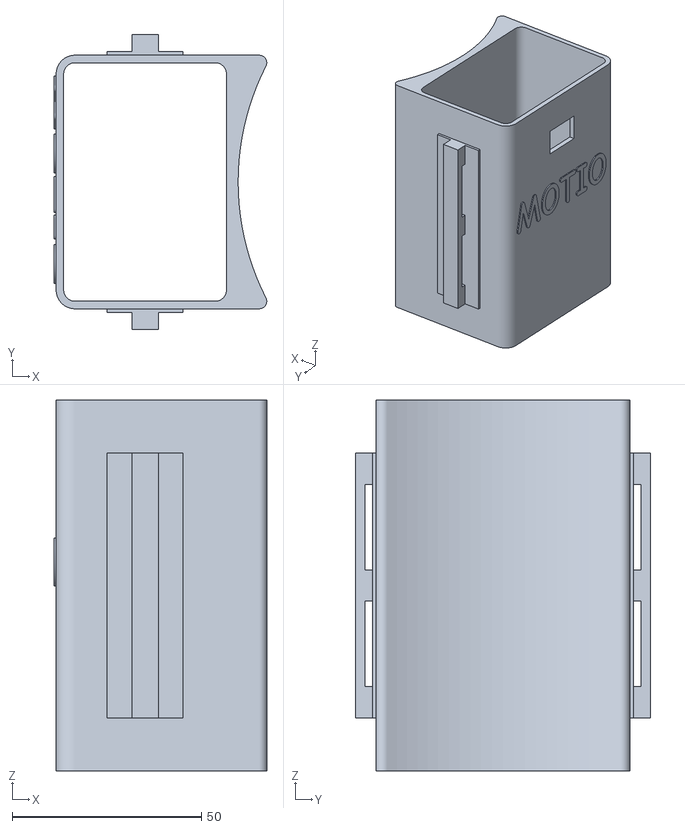
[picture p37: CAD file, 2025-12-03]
Hardware/Tobillero Modelo 3D/Caja P-new.stl
56.1 x 78.0 x 98.0

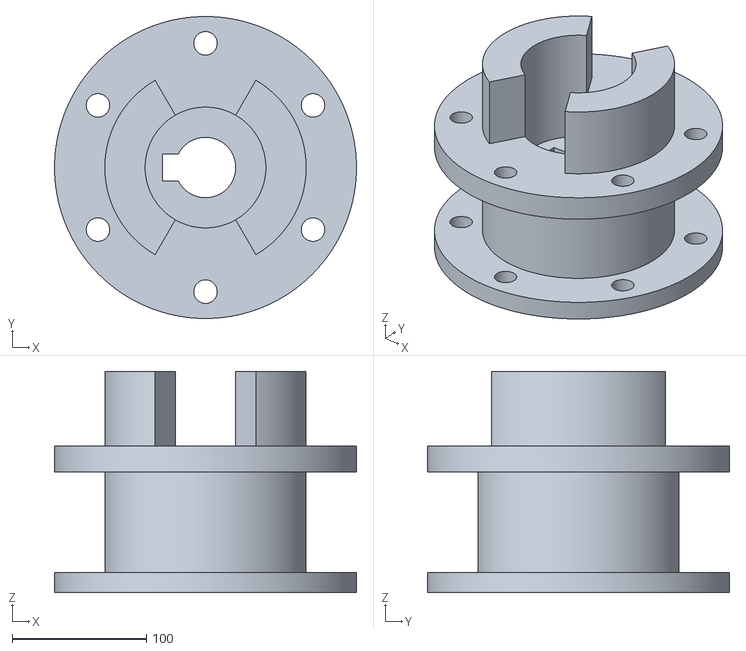
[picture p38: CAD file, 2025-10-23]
Talleres/T9/Drive Sleeve.stl
225.0 x 225.0 x 165.0

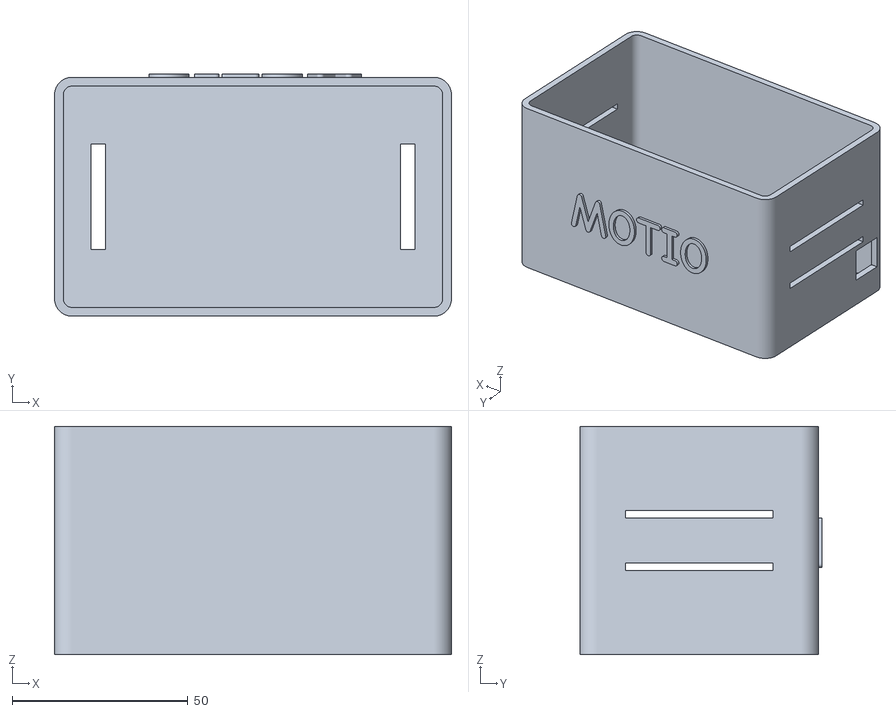
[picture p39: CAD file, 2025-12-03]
Hardware/Caja Modelo 3D/caja Cintura1- Part 1.stl
113.0 x 69.0 x 65.0

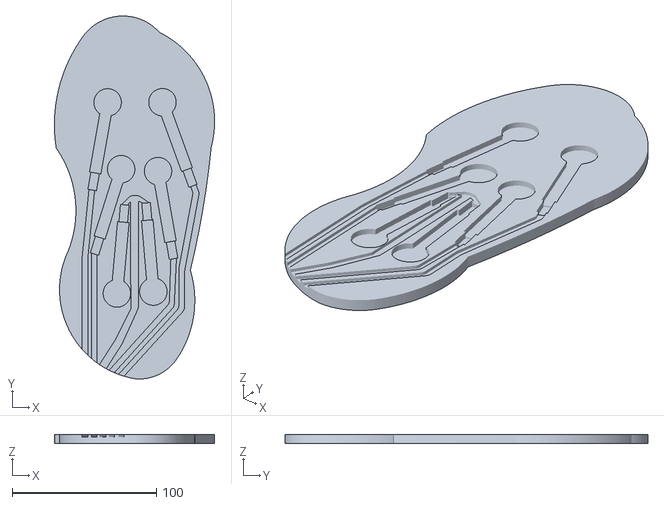
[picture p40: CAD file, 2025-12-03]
Hardware/Plantilla Modelo 3D/Parte_abajo P.stl
110.9 x 251.3 x 6.00

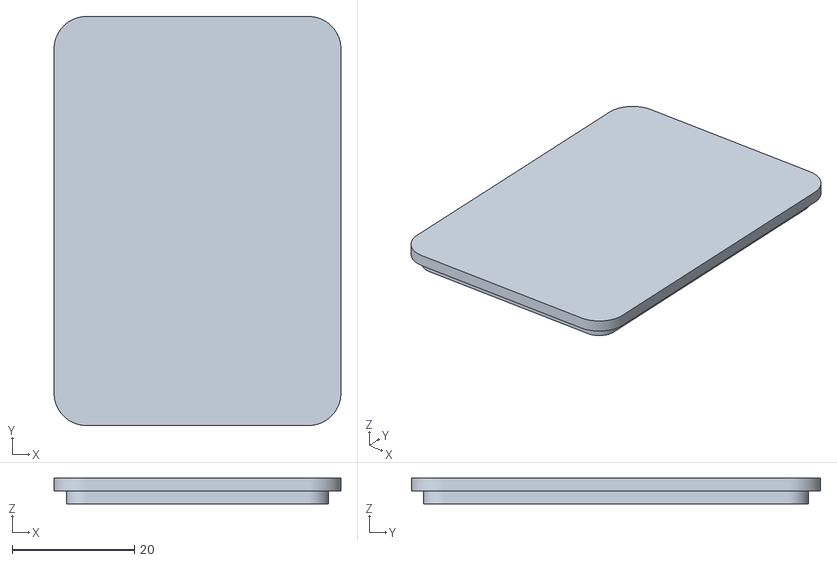
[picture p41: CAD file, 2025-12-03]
Hardware/Tobillero Modelo 3D/Tapa arriba P.stl
47.0 x 67.0 x 4.20

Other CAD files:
Hardware/Tobillero Modelo 3D/Tapa abajo P.stl

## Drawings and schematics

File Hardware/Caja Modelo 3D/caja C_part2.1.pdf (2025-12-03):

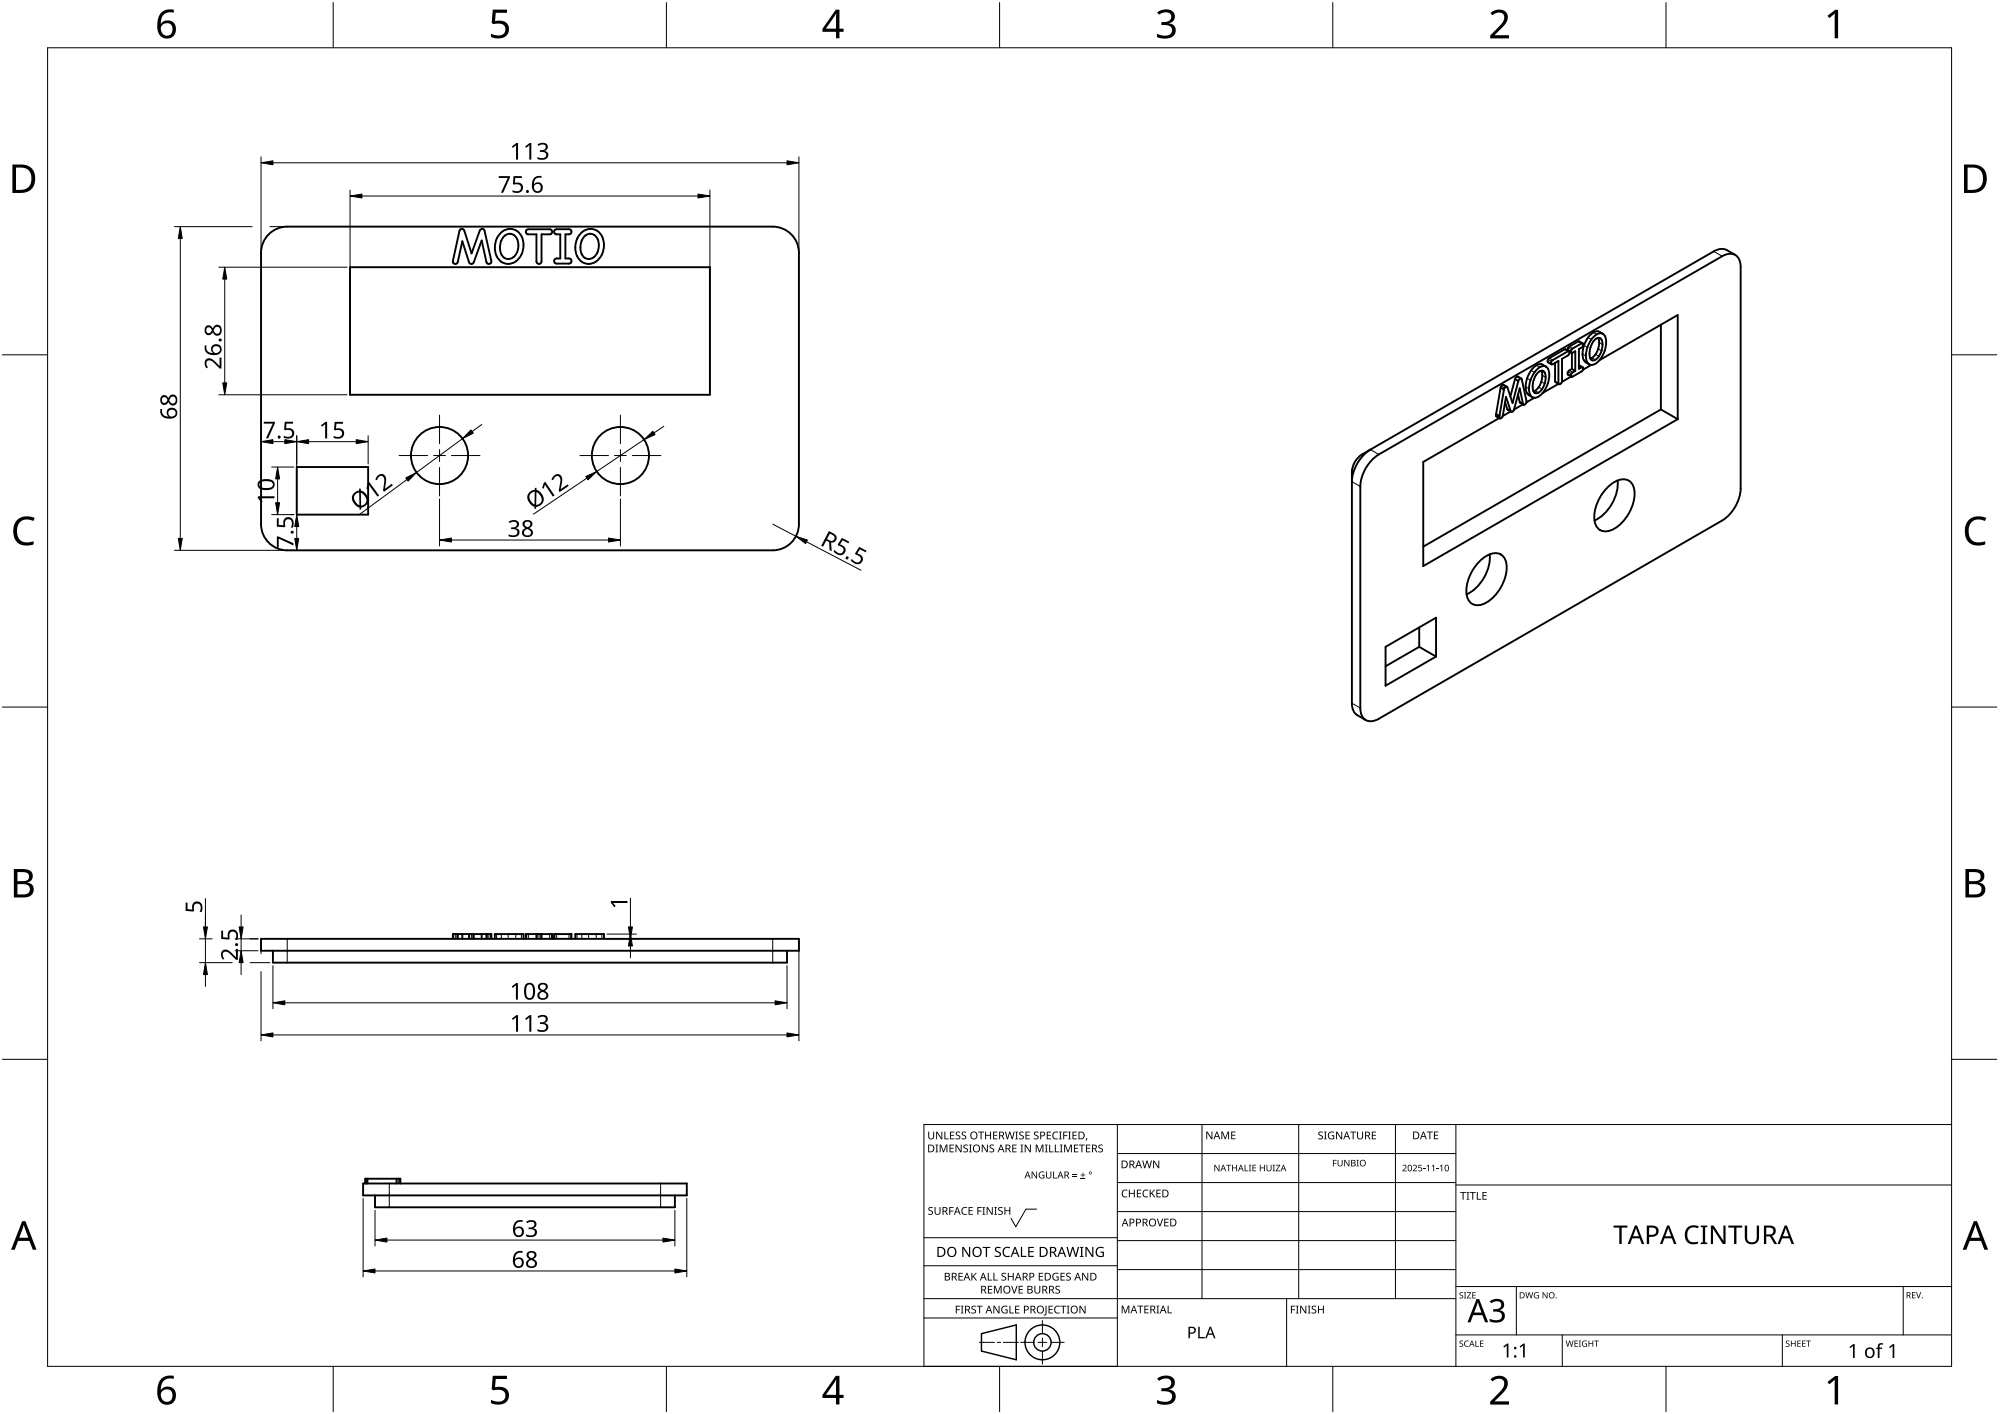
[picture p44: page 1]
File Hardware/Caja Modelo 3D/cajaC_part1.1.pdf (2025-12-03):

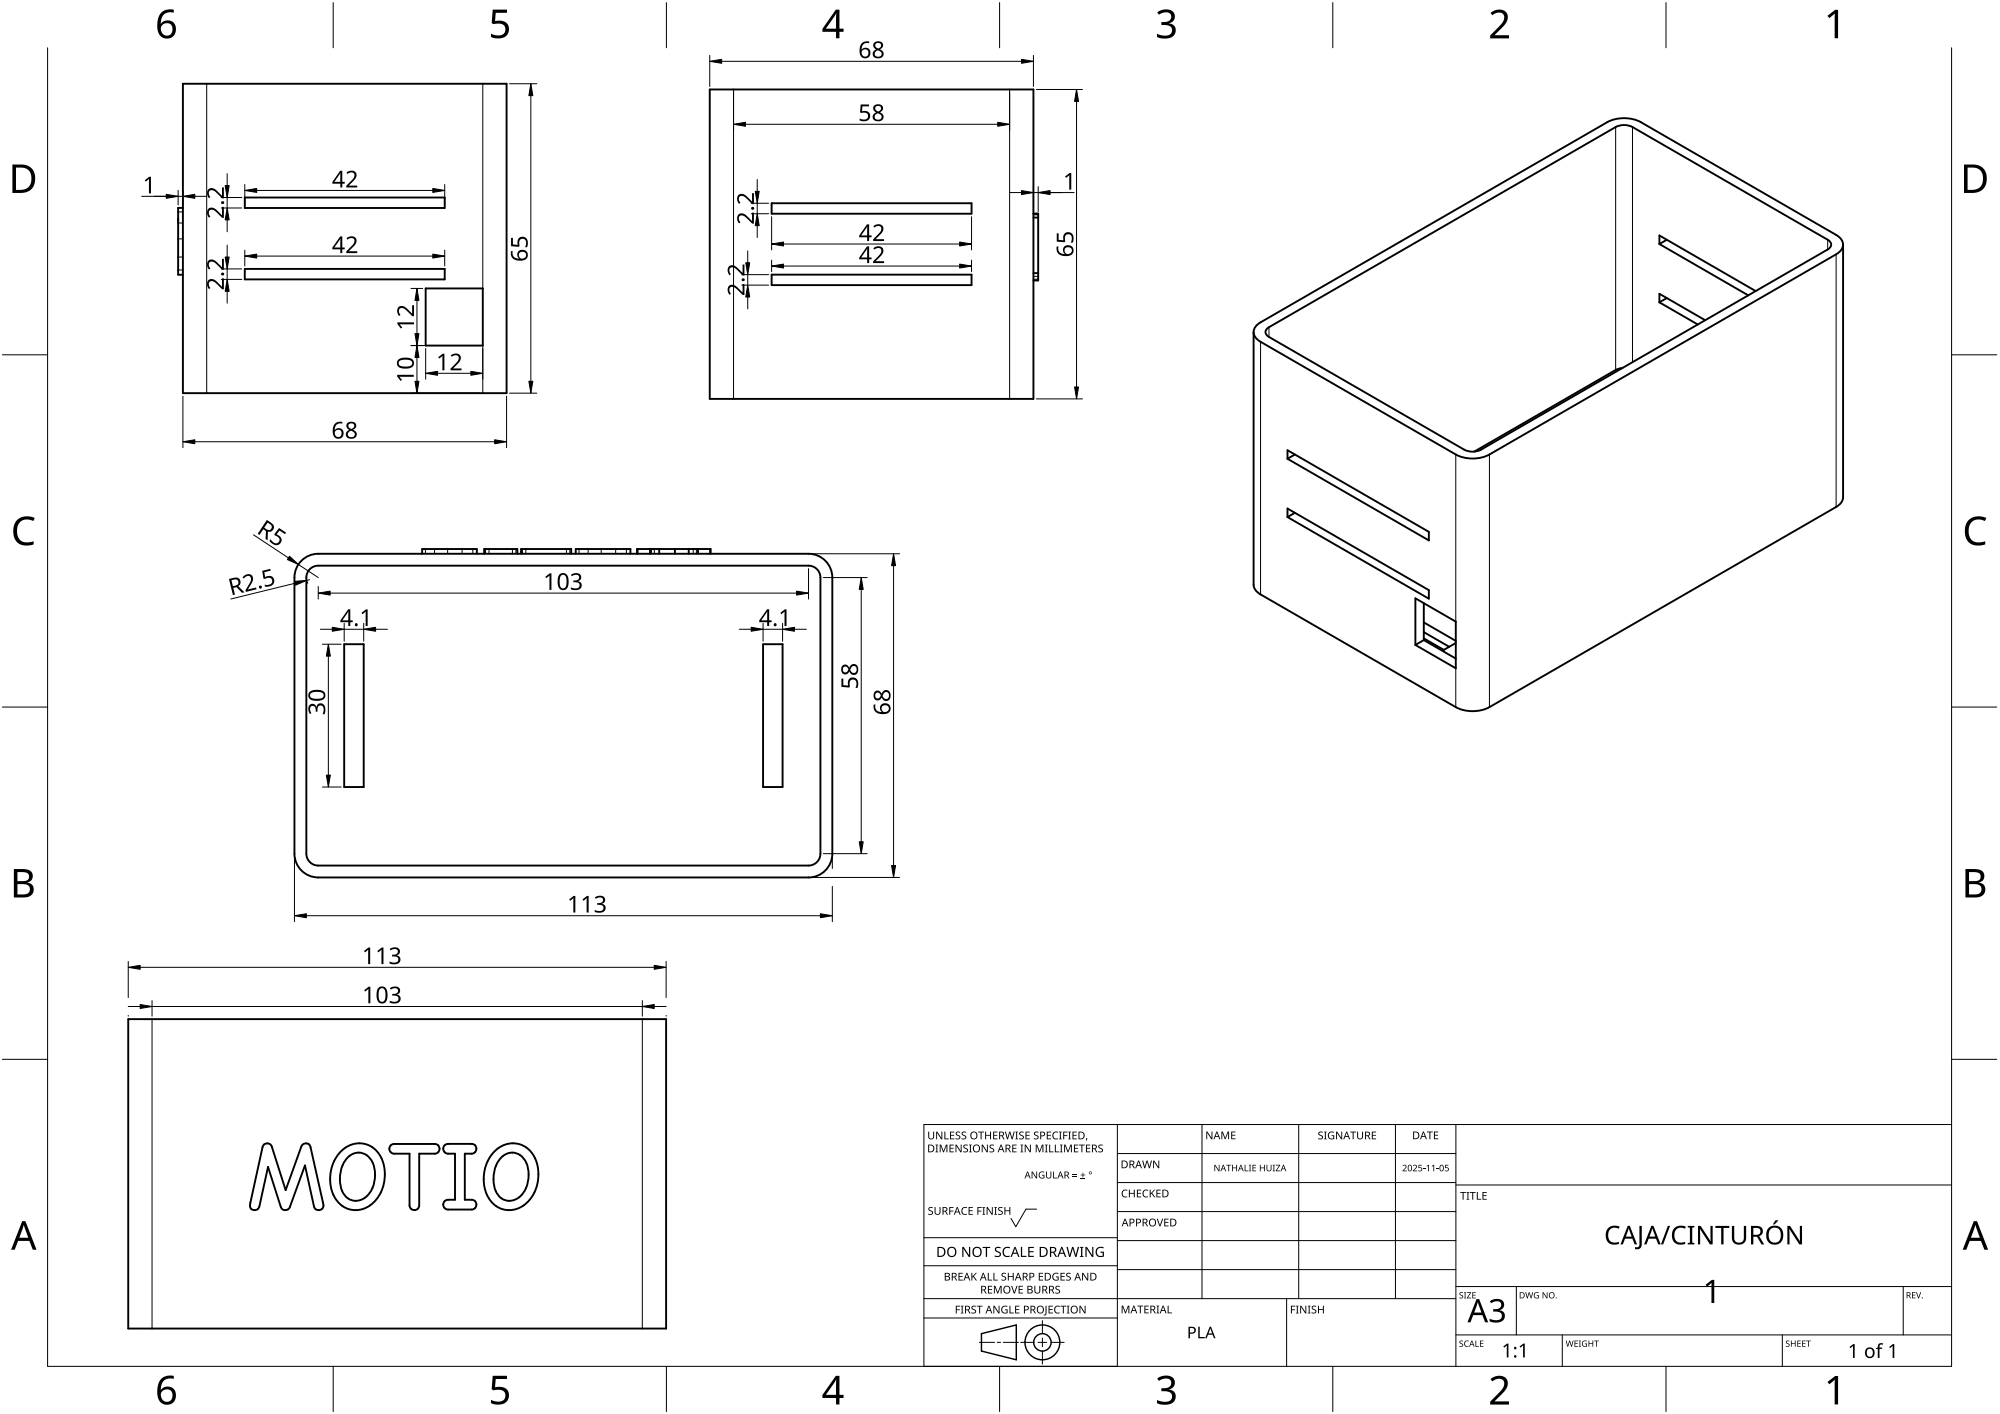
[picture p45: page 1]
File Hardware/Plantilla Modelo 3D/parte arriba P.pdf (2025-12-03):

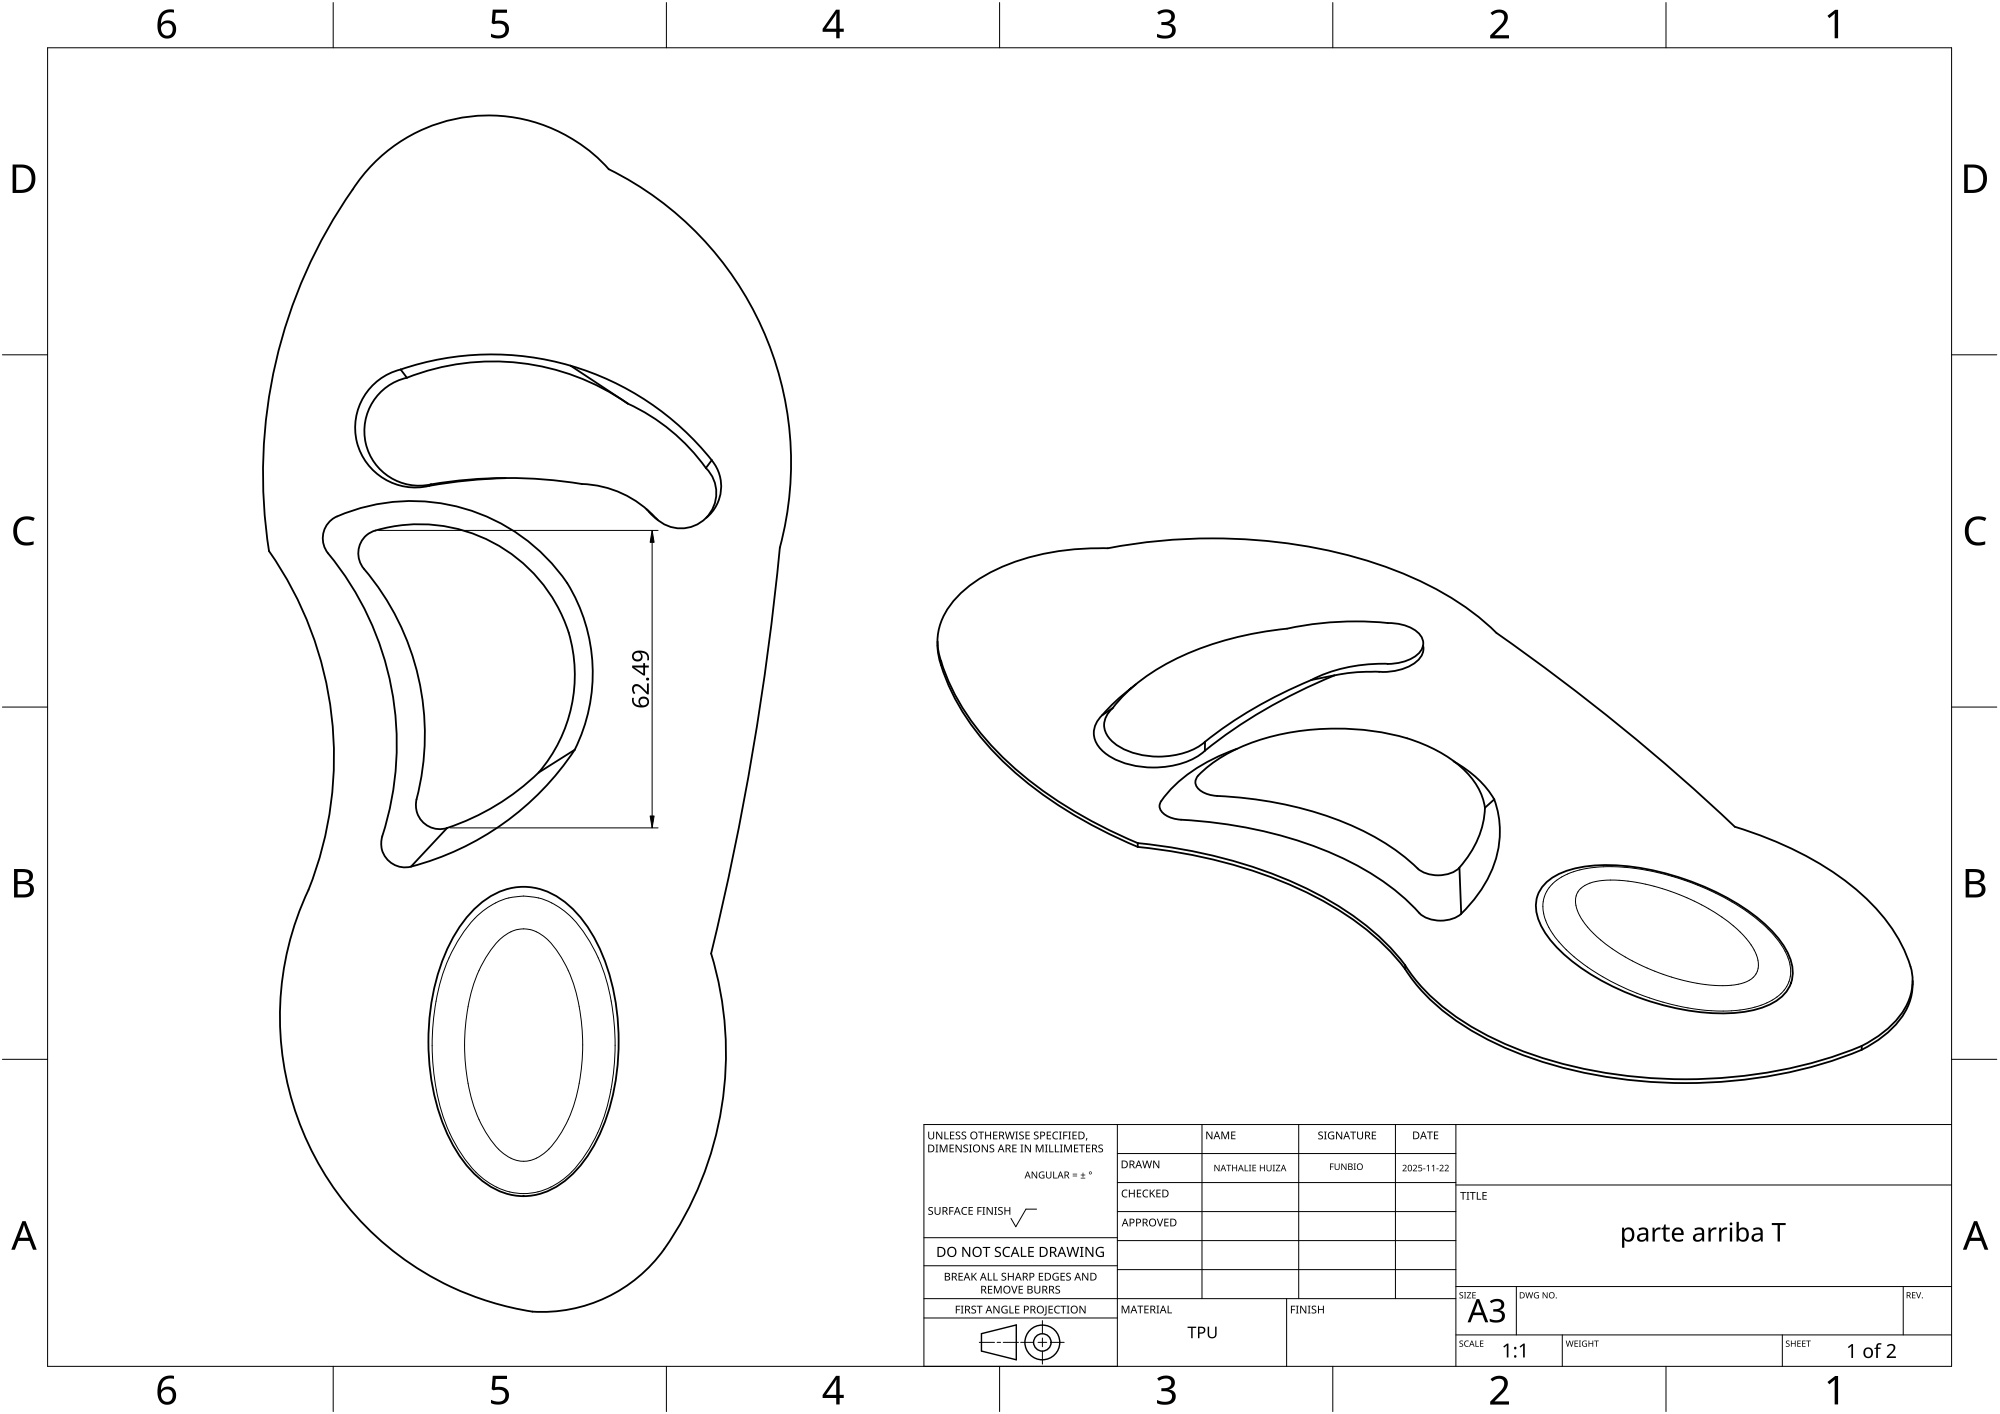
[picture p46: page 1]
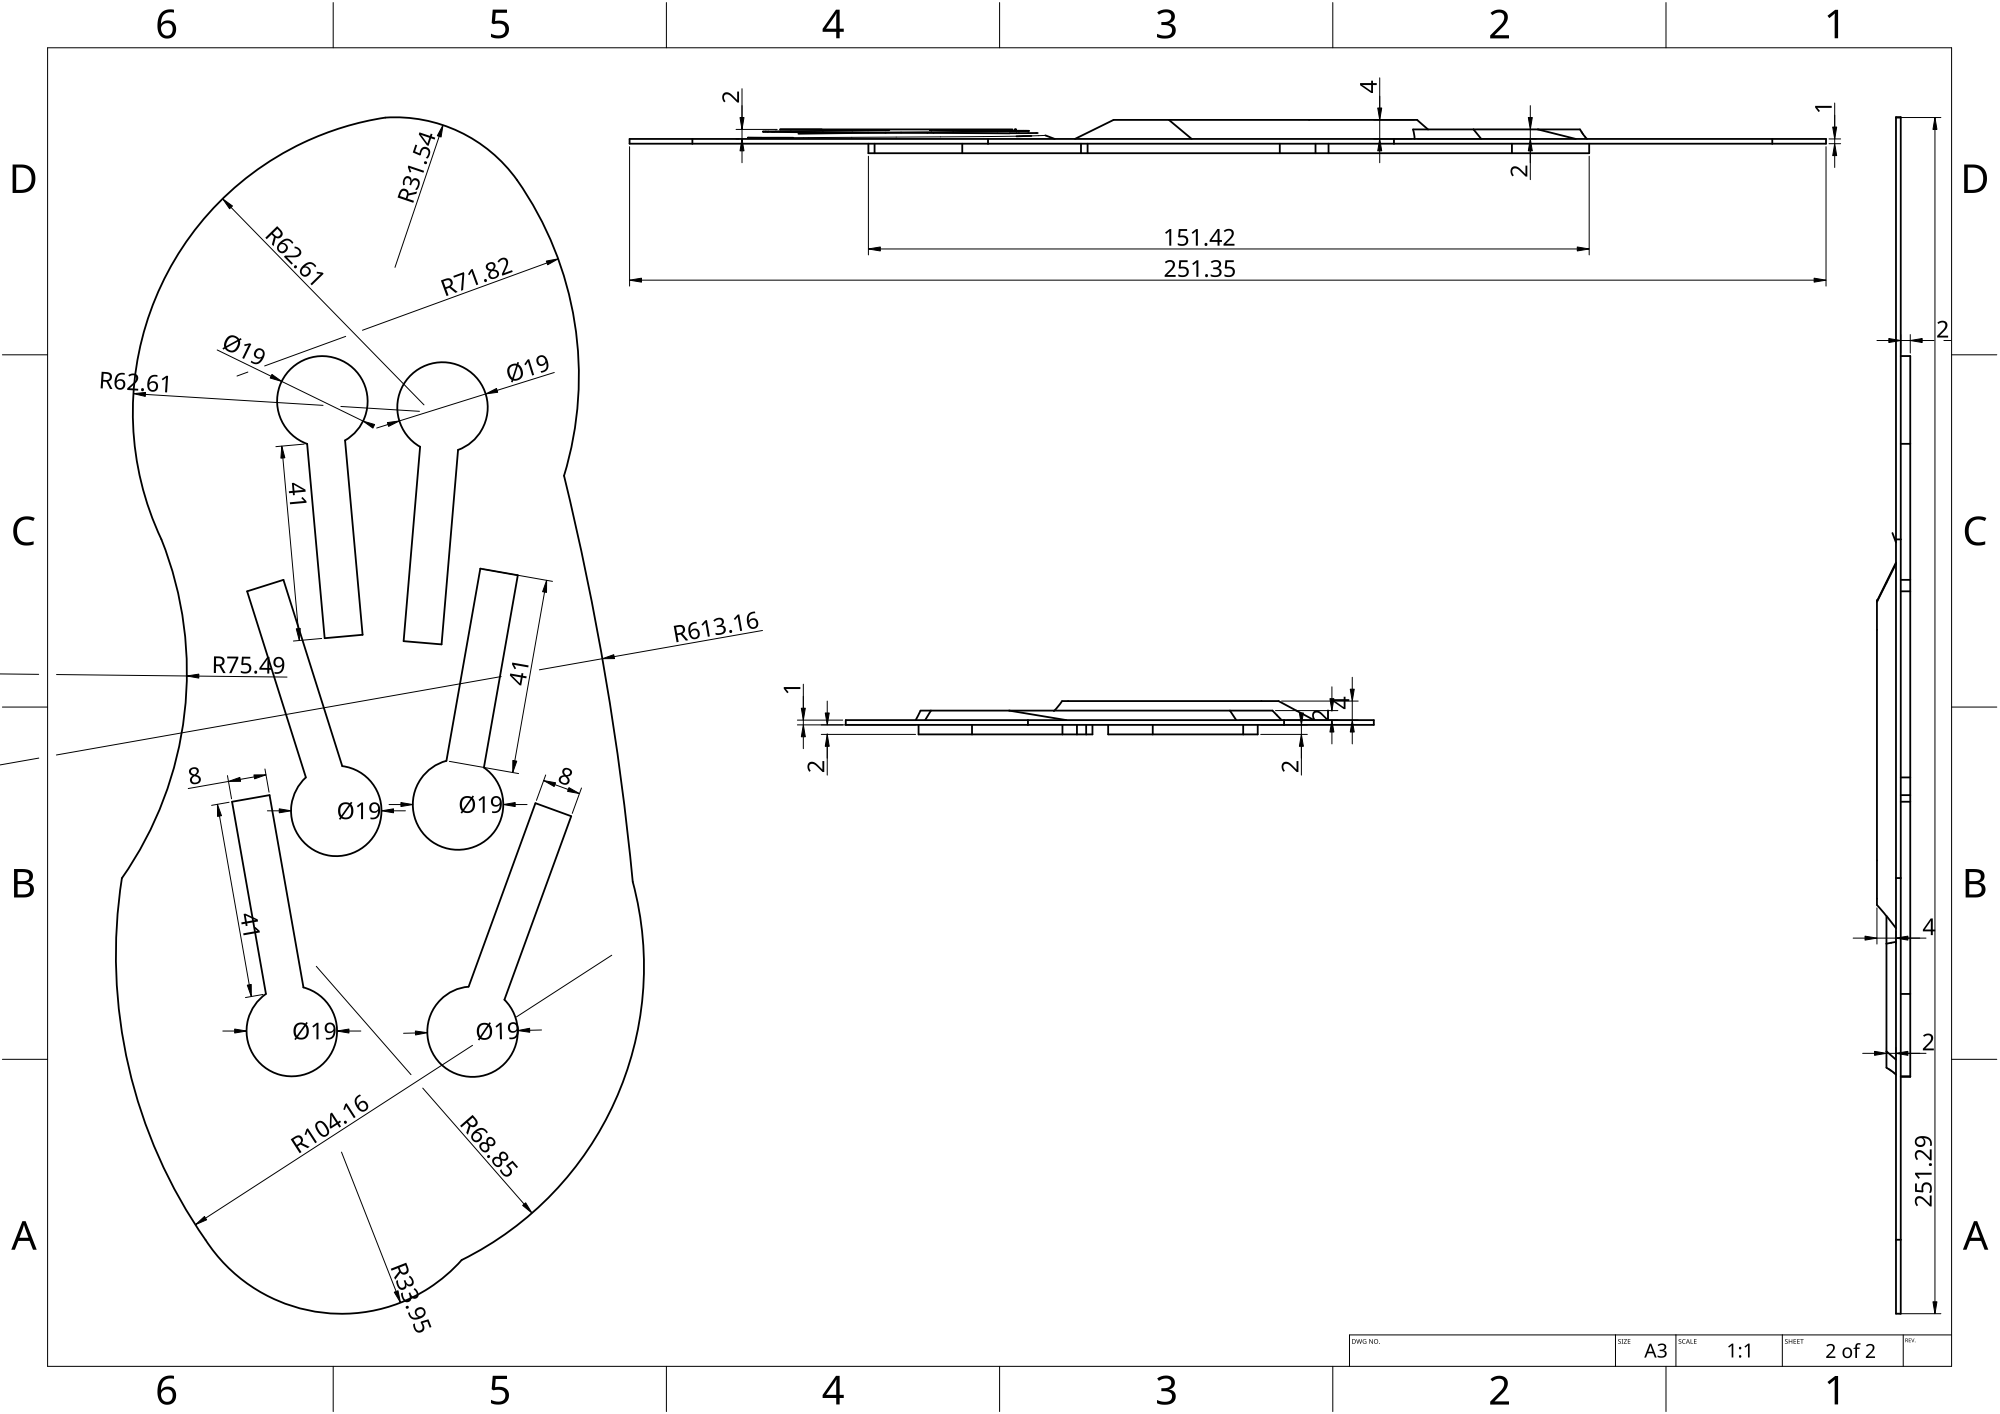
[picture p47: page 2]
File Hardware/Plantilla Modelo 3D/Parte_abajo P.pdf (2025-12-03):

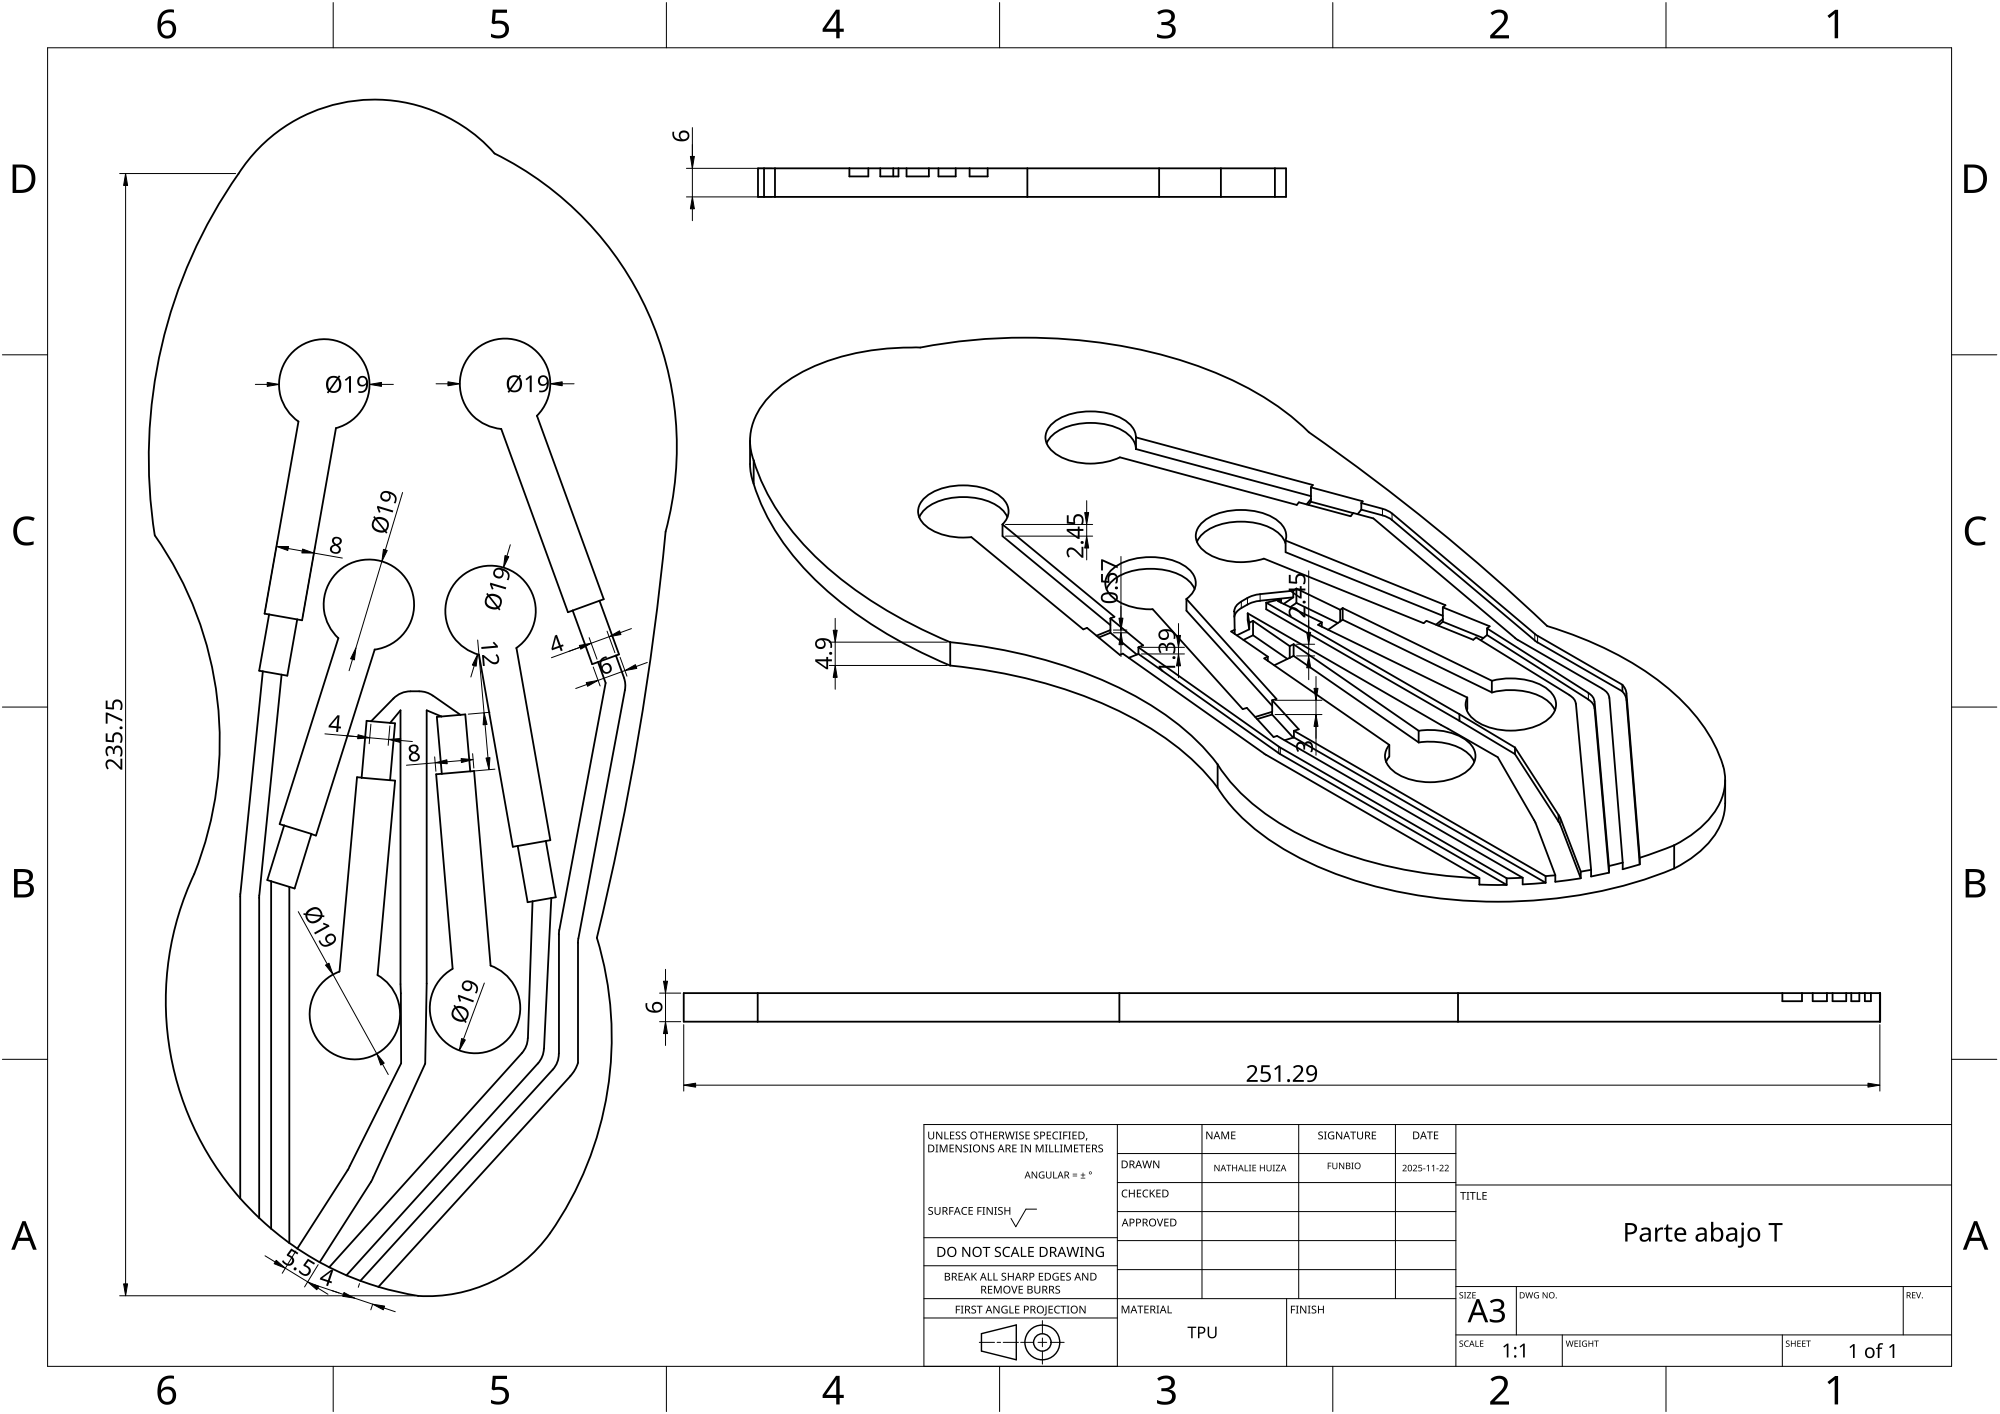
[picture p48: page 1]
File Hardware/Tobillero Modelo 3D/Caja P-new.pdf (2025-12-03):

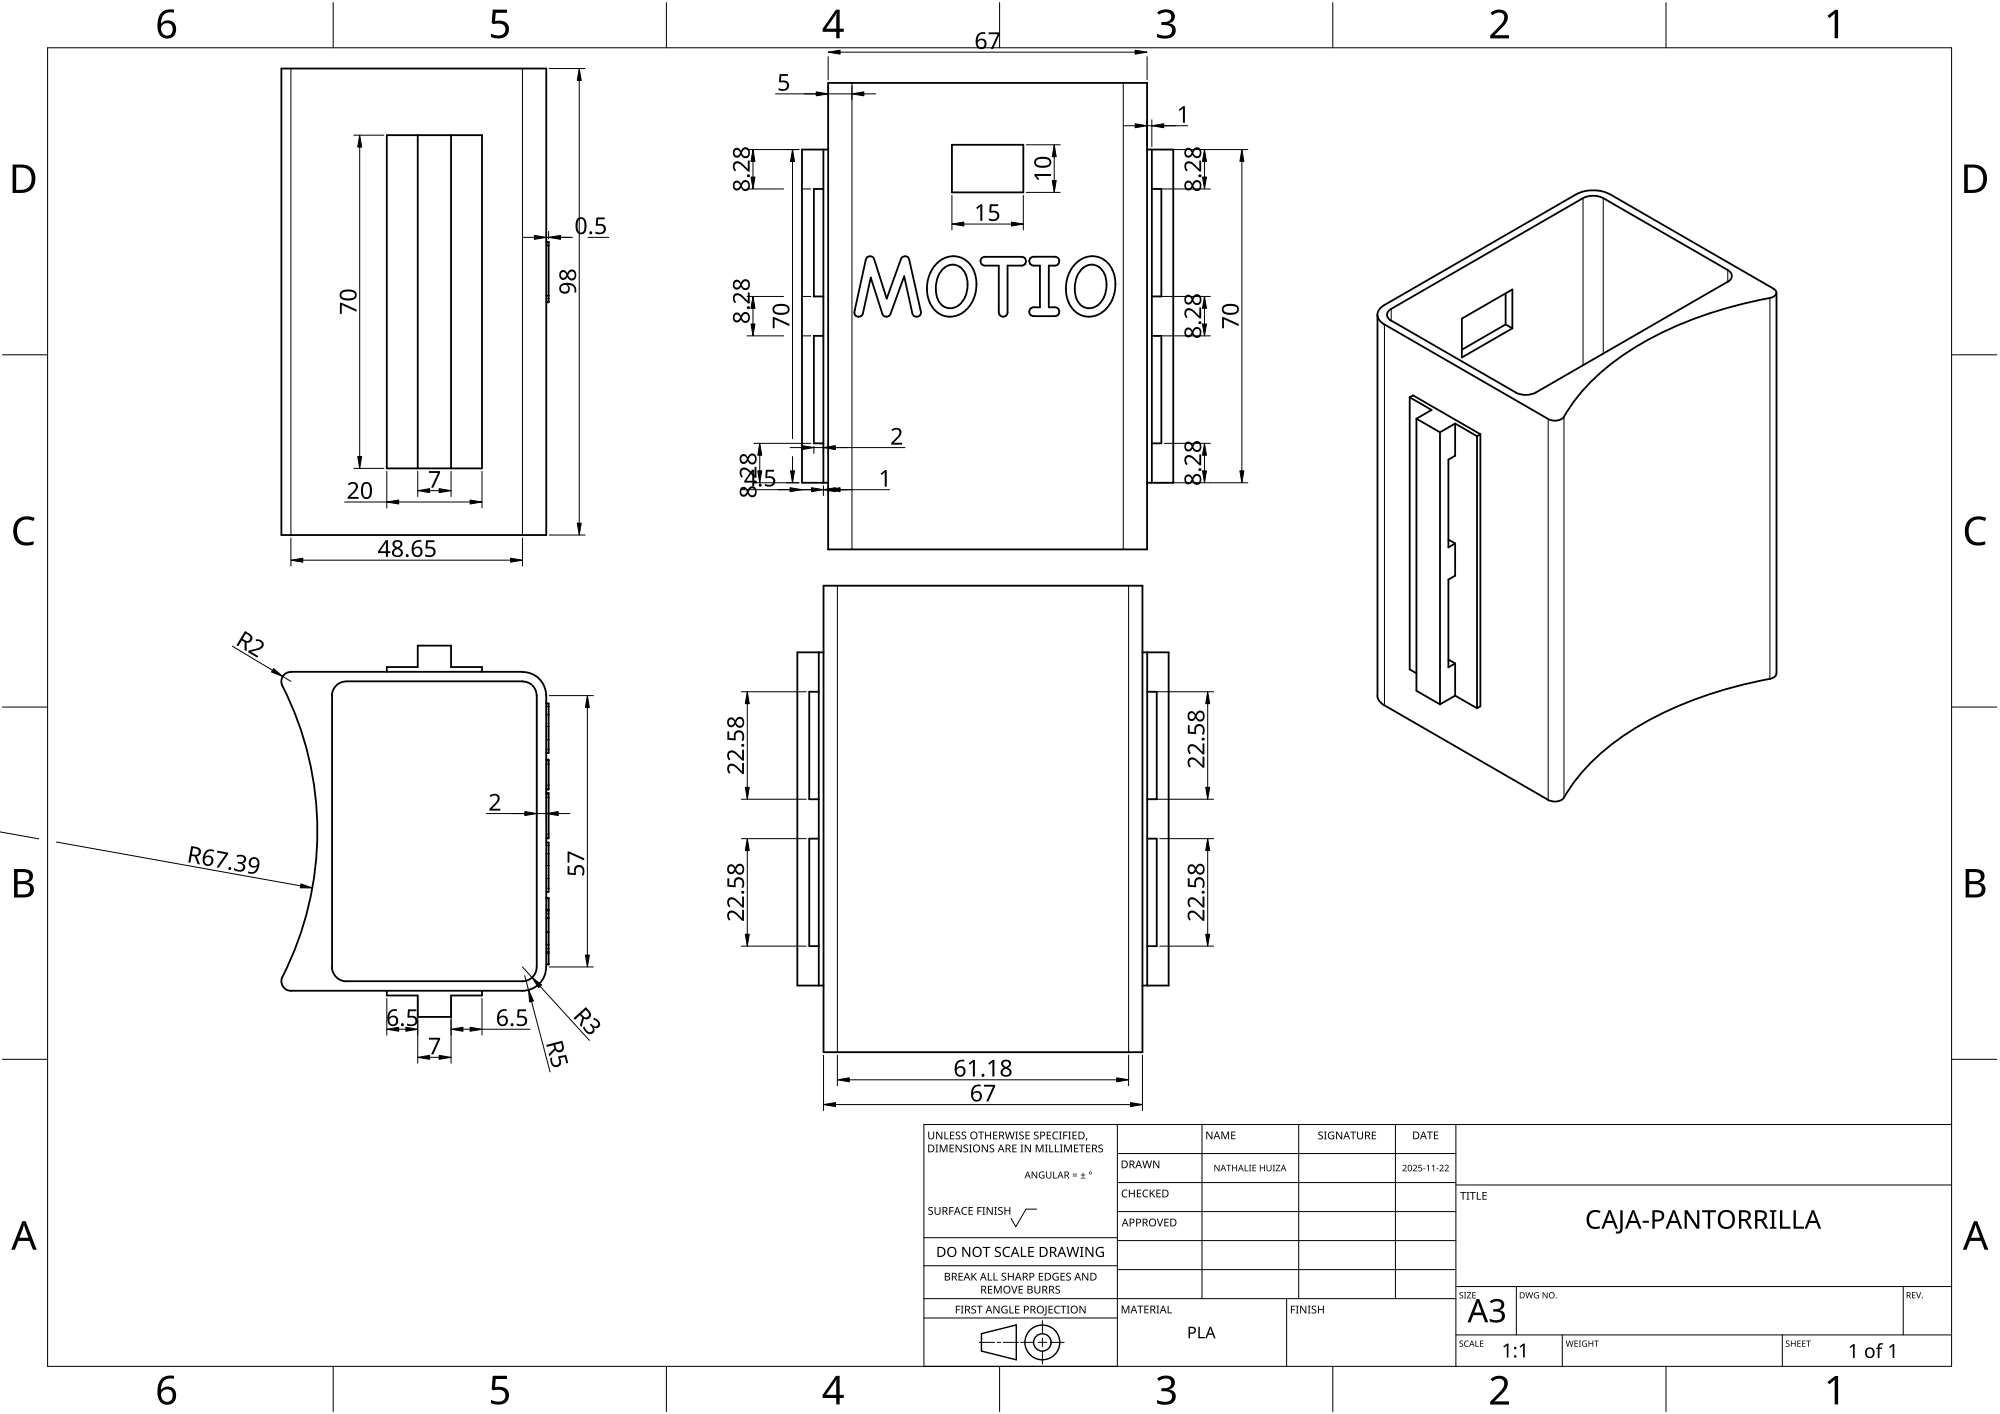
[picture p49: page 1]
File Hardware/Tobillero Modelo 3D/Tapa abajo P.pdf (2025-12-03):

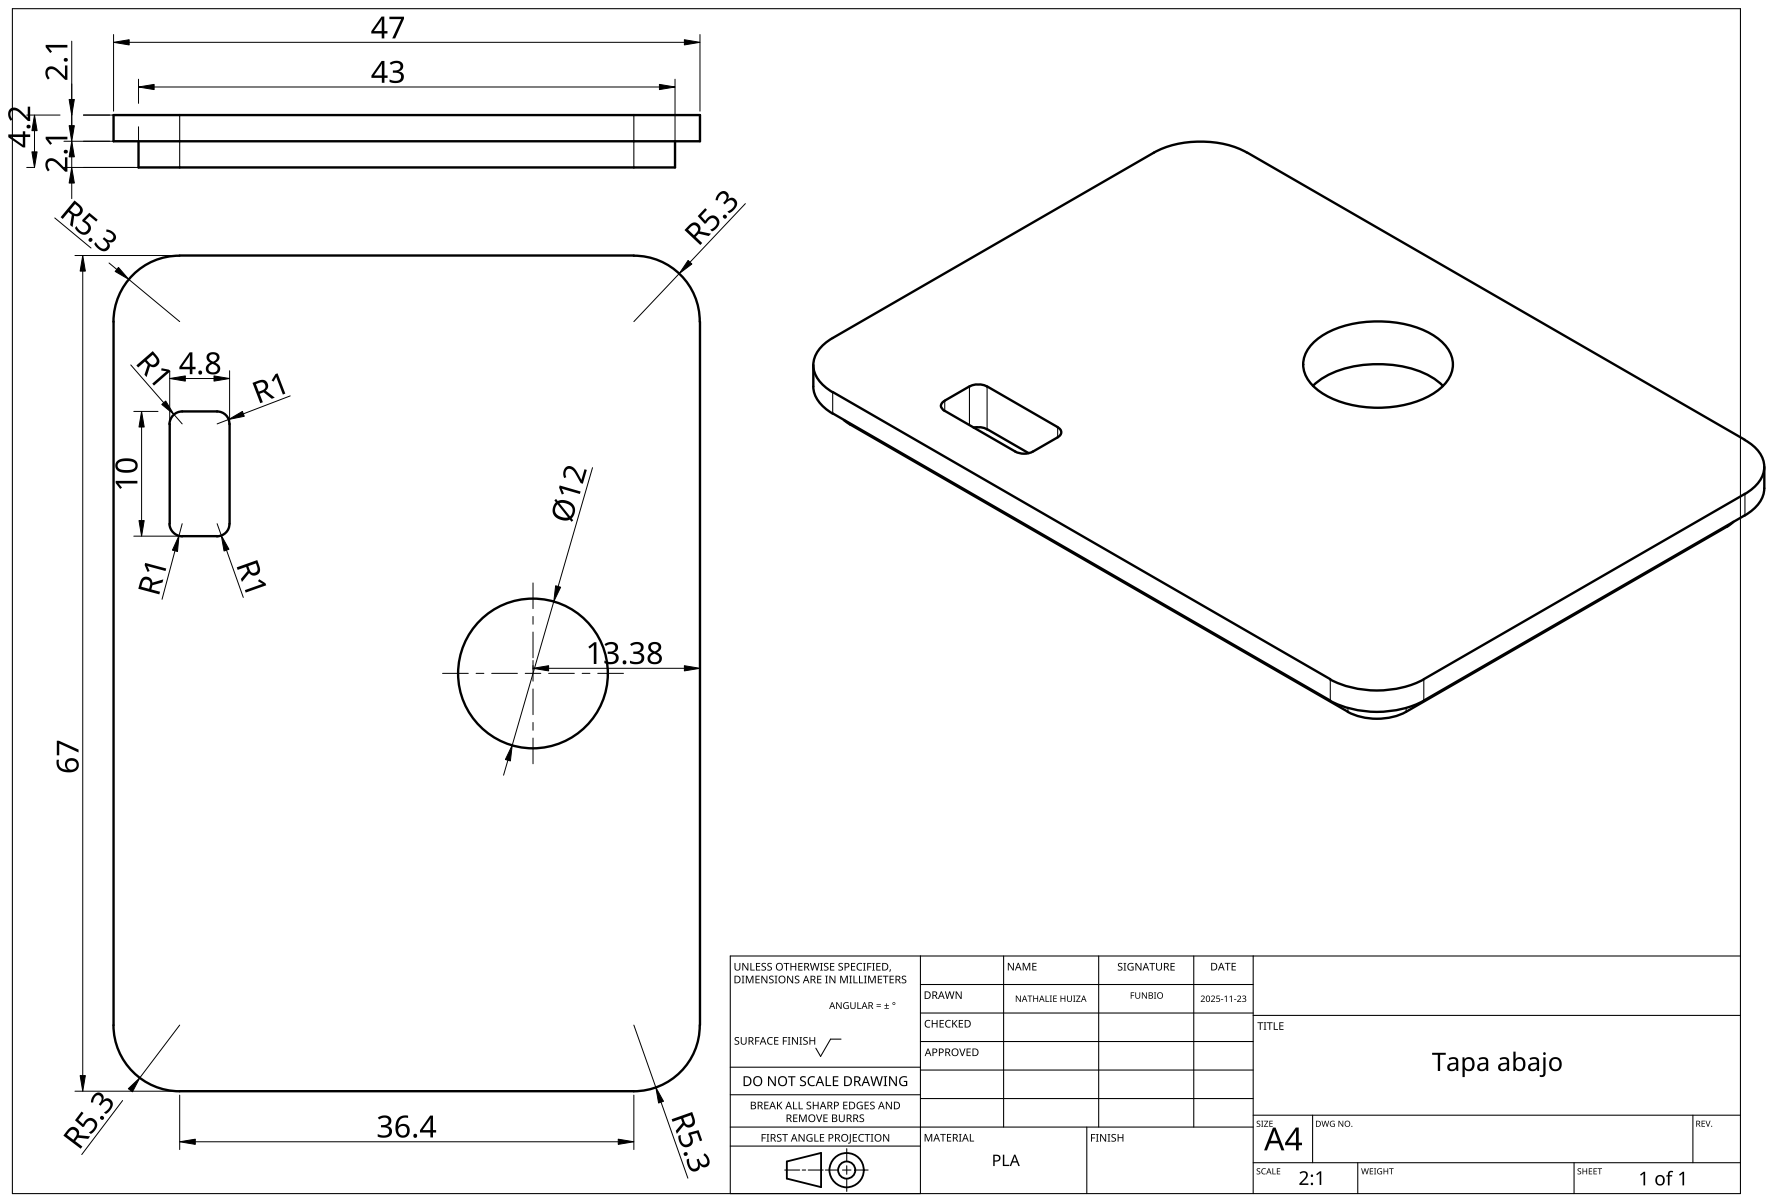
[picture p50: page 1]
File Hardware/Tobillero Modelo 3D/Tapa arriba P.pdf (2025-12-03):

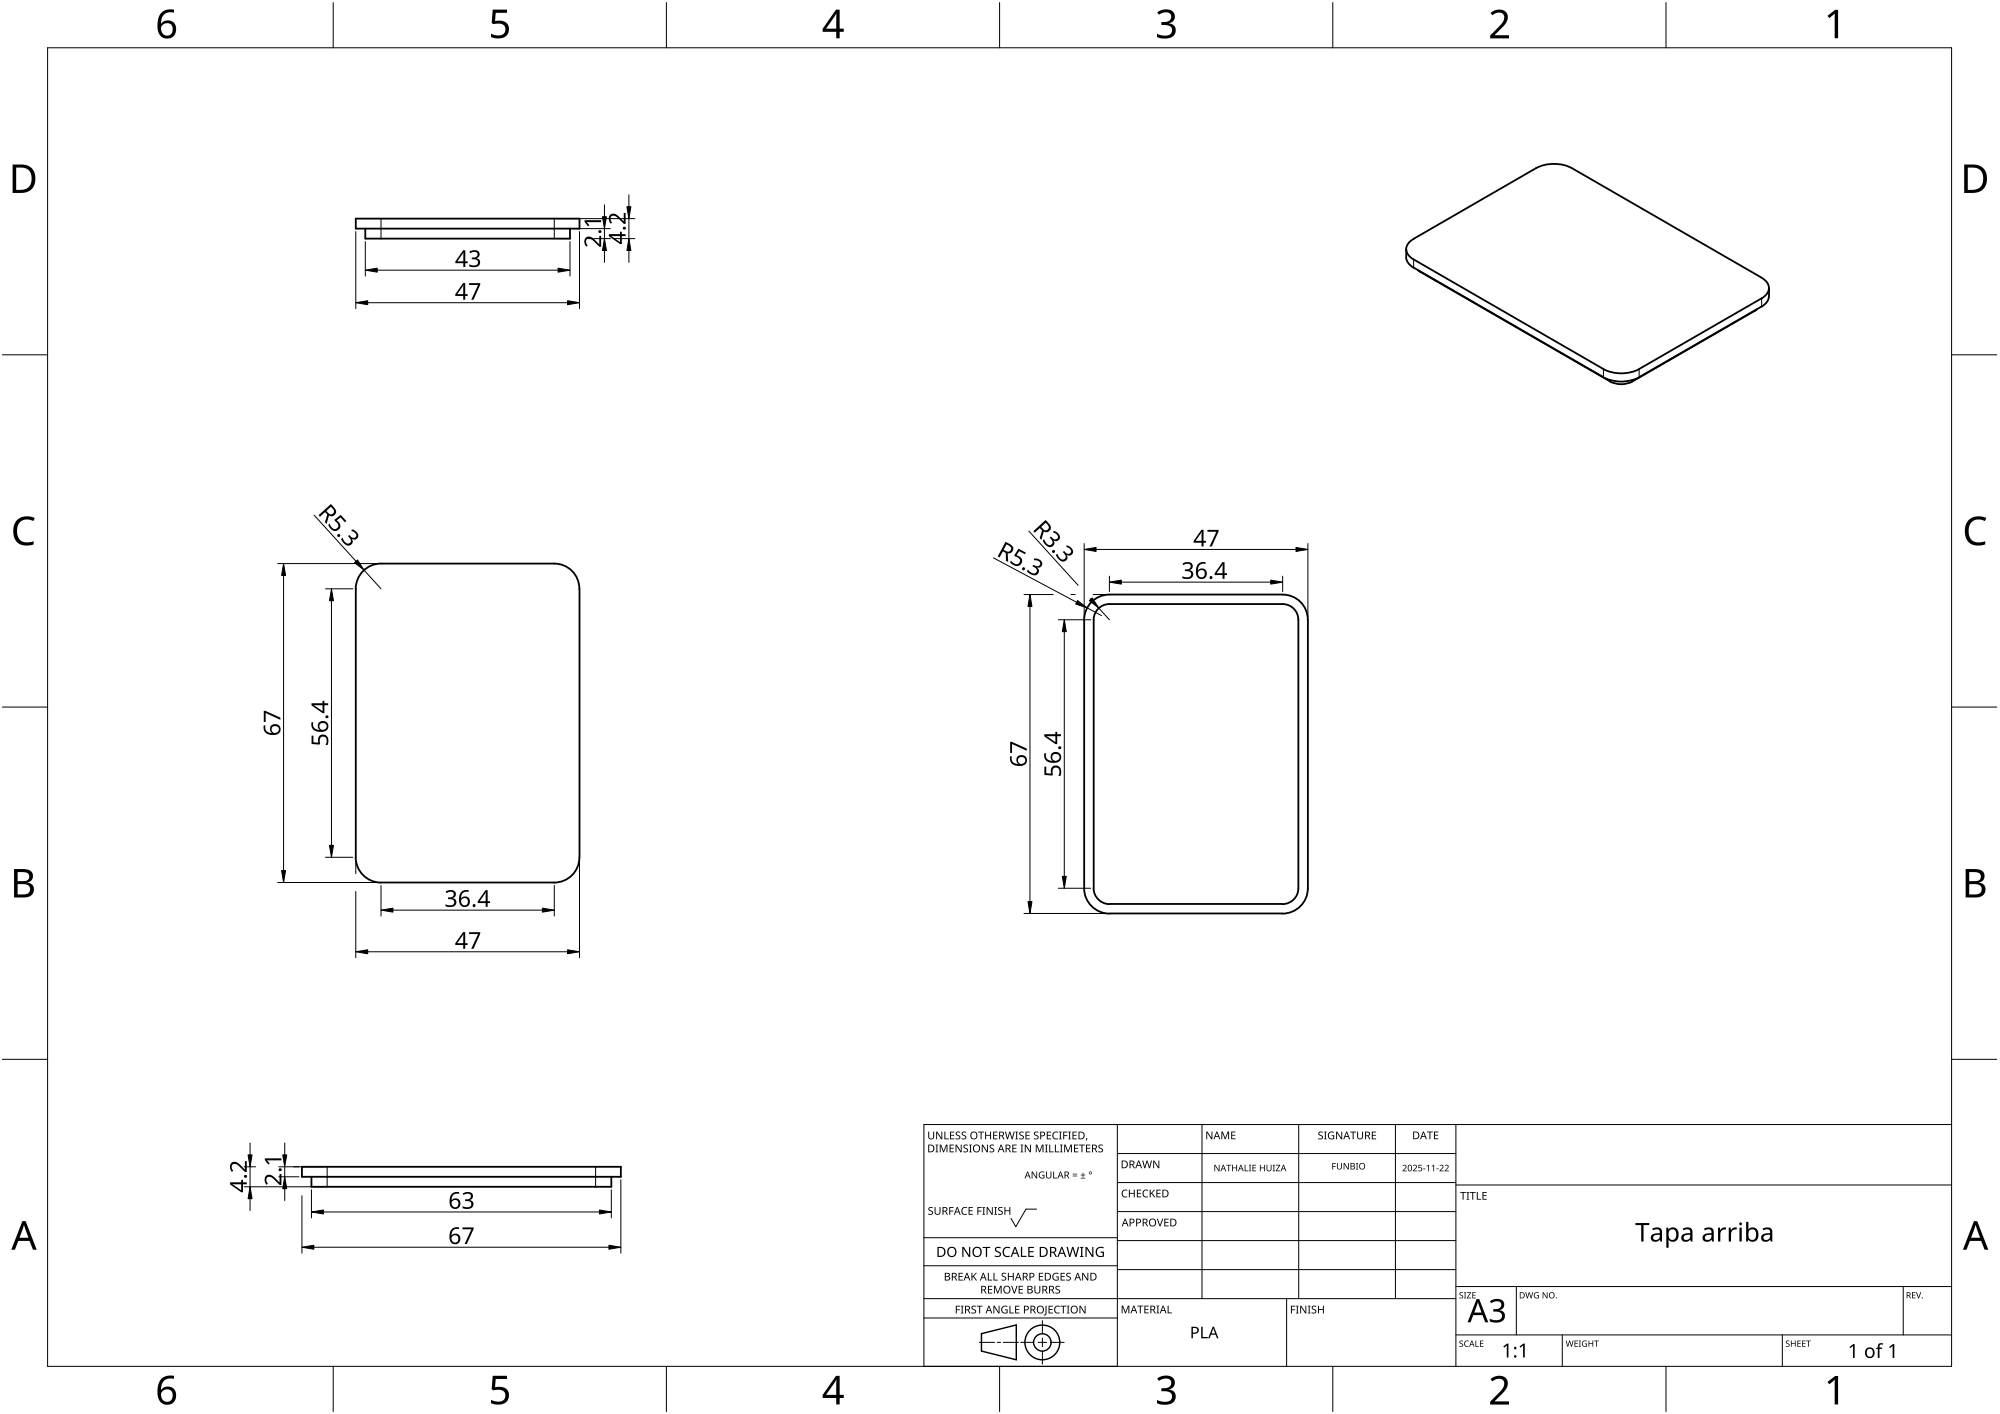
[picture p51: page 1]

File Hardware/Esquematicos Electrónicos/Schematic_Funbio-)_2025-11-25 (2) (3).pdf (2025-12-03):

## ENERGIZADO-CARGADO-REGULACION DE VOLTAJE ARDUINO UNO

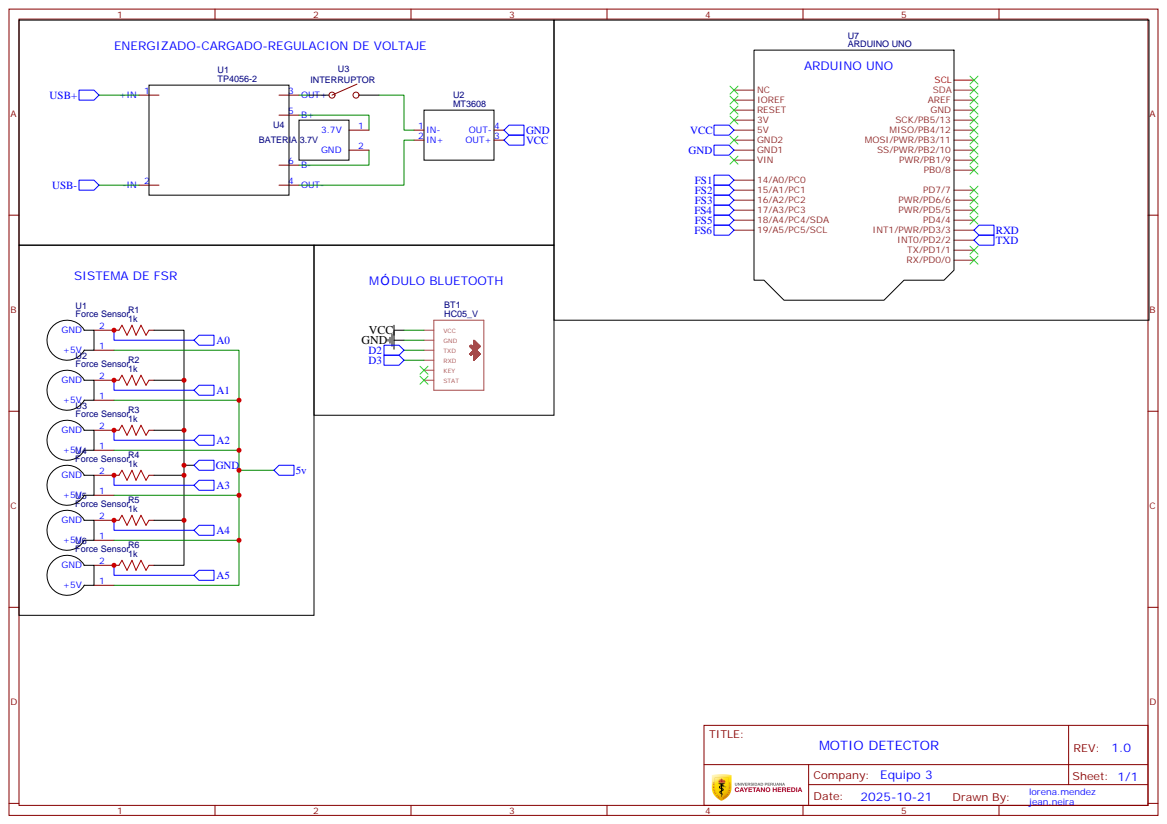
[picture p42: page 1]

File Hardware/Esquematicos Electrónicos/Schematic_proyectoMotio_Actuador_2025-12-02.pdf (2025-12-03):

## MICROCONTROLADOR PANTALLA LCD

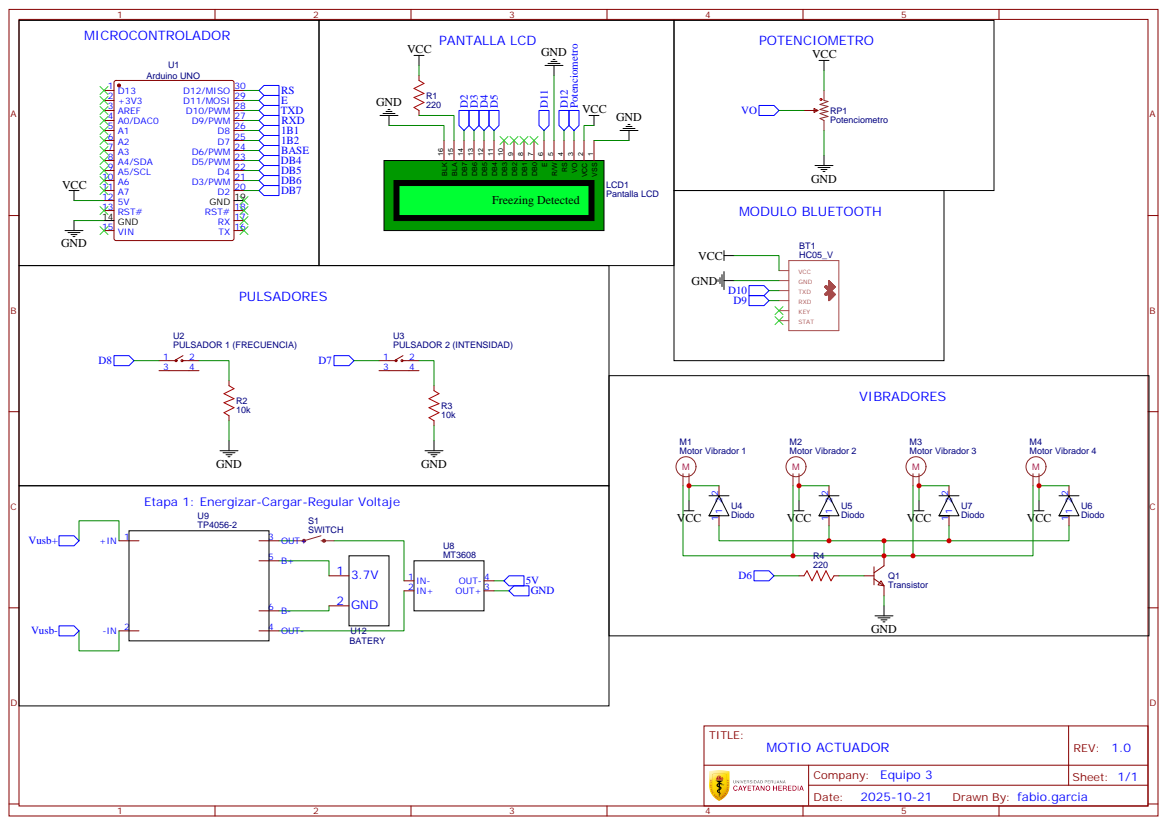
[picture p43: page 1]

Etapa 1: Energizar-Cargar-Regular Voltaje

Drawn By: fabio.garcia
